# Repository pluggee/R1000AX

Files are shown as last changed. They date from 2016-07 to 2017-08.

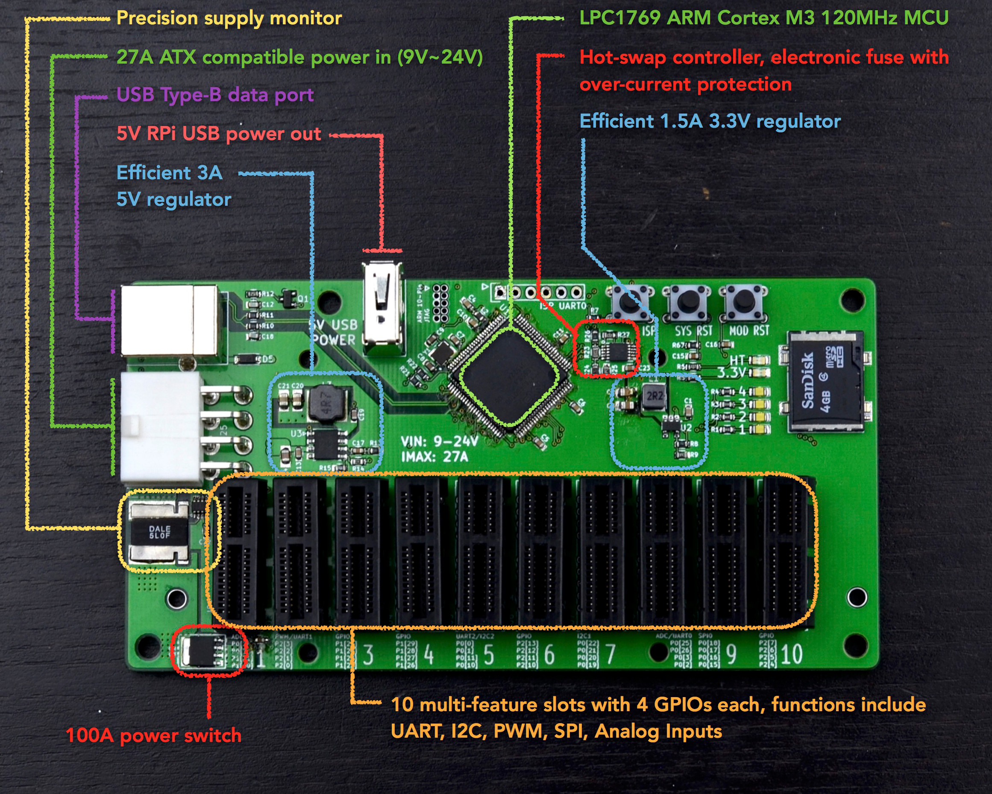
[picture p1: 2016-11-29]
doc/R1000A-10 Illustration.jpg

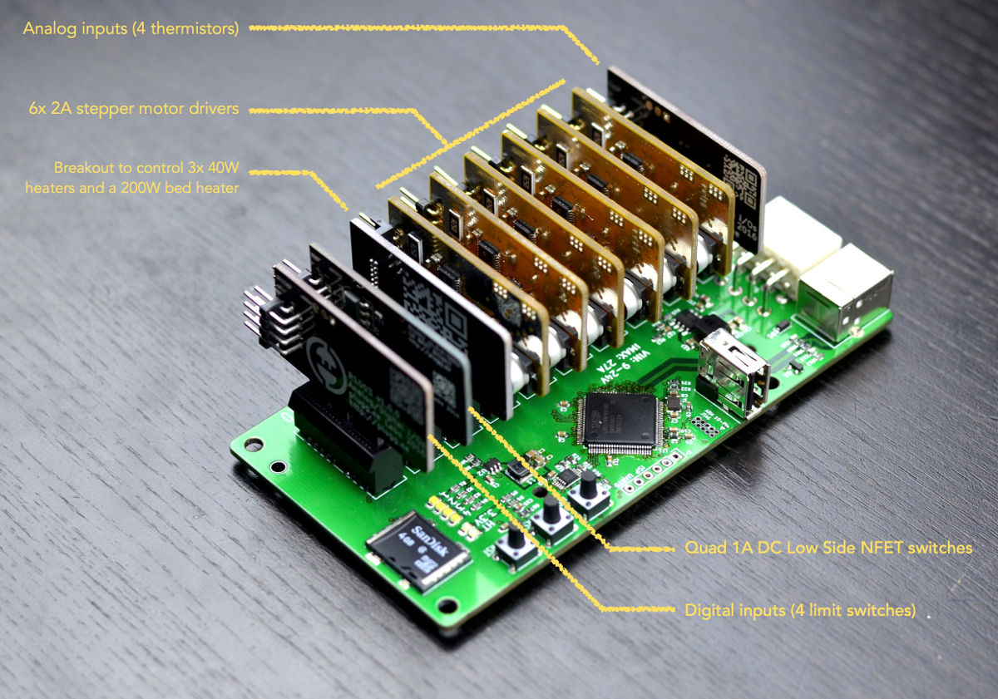
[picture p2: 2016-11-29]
doc/R1000A-10-populated.jpg

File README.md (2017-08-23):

JuicyBoard Robotics Platform
=======================
Overview
--------

This repository contains all PCB and firmware design resources for the R1000 robotics platform base boards and modules

File Structure
--------------
<pre>
(d) pcb	        : KiCAD PCB files
(d) firmware    : firmare for all modules
(d) doc         : documentation
(f) README.md   : Markdown README file
</pre>

Boards
------
Feature Boards
<pre>
R1000A 	        : Base Platform Board (2 variants, R1000AX and R1000A)
R1001		: Cascadable Stepper Motor Driver
R1002		: Quad 1A DC Low Side NFET Control Switches
R1003		: Analog/Digital I/O (Analog/Digital)
R1004		: Inertial Measurement Unit (IMU) Breakout
R1005		: General Purpose Breakout/Extension
R1006 		: SD Card
R1007		: Quad 20A DC Low Side NFET Control Switches
R1008		: Dual/Quad PT100 Platinum RTD temperature sensing module
</pre>
Adapters
<pre>
R1200		: Stepper Motor Master/Slave Bond
</pre>
Interposers
<pre>
R1100           : C.H.I.P. Pro Interposer with Host USB 2.0 and MicroSD
R1101           : particle.io photon Interposer
R1102           : particle.io electron Interposer
R1103           : Raspberry Pi data/power Interposer
</pre>
Special Boards
<pre>
R1000DBG	: Busy Bee Debug/Programming Board
</pre>
Setup Steps
-----------
Make sure to do the following before starting a project

1. Clone (or update) [KiCADLibs](https://github.com/pluggee/KiCADLibs) locally IN THE SAME DIRECTORY AS THIS REPO, this will include the required schematic symbols
2. Clone (or update) [pack3d](https://github.com/pluggee/pack3d) repo, this will include 3D models for PCB 3D view
3. Set KISYS3DMOD variable to point to your local **pack3d** repo, you can do this in the main KiCAD window by

**Preferences** -> **Configure Paths**

License
-------
R1000A board design files are released under the GNU GPL v3, which you can find at <http://www.gnu.org/licenses/gpl-3.0.en.html>,
Check License.md for more details.

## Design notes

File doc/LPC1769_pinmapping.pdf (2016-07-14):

Pin Name

LQFP100 Pin

Smoothie Board Reserved

Reconfgurable?

ADC Input

I2C

SPI

TDO/SWO

1

1
TDI

2

1
TMS/SWDIO

3

1
TRST

4

1
TCK/SWDCLK

5

1
P0[26]/AD0[3]/AOUT/RXD3

6

1

1
P0[25]/AD0[2]/I2SRX_SDA/TXD3

7

1

1
P0[24]/AD0[1]/I2SRX_WS/CAP3[1]

8

1

1
P0[23]/AD0[0]/I2SRX_CLK/CAP3[0]

9

1

1
10

1
11

1
VREFP | 12

1
n.c. | 13

1
RSTOUT | 14

1
VREFN | 15

1
RTCX1 | 16

1
RESET | 17

1
RTCX2 | 18

1
VBAT | 19

1
P1[31]/SCK1/AD0[5] | 20

1

1
| 21

1

1
XTAL1 | 22

1
XTAL2 | 23

1
P0[28]/SCL0/USB_SCL | 24

1
P0[27]/SDA0/USB_SDA | 25

1
P3[26]/STCLK/MAT0[1]/PWM1[3] | 26

1
P3[25]/MAT0[0]/PWM1[2] | 27

1
| 28

1
P0[29]/USB_D+ | 29

1
P0[30]/USB_D | 30

1
| 31

1
P1[18]/USB_UP_LED/PWM1[1]/CAP1[0] | 32

1

VDDA VSSA

P1[30]/VBUS/AD0[4] VDD(3V3) VSS

33

1
P1[20]/MCI0/PWM1[2]/SCK0 | 34

1
P1[21]/MCABORT/PWM1[3]/SSEL0 | 35

1
P1[22]/MCOB0/USB_PWRD/MAT1[0] | 36

1
P1[23]/MCI1/PWM1[4]/MISO0 | 37

1

1
P1[24]/MCI2/PWM1[5]/MOSI0 | 38

1

1
P1[25]/MCOA1/MAT1[1] | 39

1
P1[26]/MCOB1/PWM1[6]/CAP0[0] | 40

1
| 41

1
| 42

1
| 43

1
P1[28]/MCOA2/PCAP1[0]/MAT0[0] | 44

1
P1[29]/MCOB2/PCAP1[1]/MAT0[1] | 45

1
P0[0]/RD1/TXD3/SDA1 | 46

1

1
P0[1]/TD1/RXD3/SCL1 | 47

1

1
P0[10]/TXD2/SDA2/MAT3[0] | 48

1

1
P0[11]/RXD2/SCL2/MAT3[1] | 49

1

1
P2[13]/EINT3/I2STX_SDA | 50

1
P2[12]/EINT2/I2STX_WS | 51

1
P2[11]/EINT1/I2STX_CLK | 52

1
P2[10]/EINT0/NMI | 53

1
| 54

1
| 55

1
P0[22]/RTS1/TD1 | 56

1
P0[21]/RI1/RD1 | 57

1
P0[20]/DTR1/SCL1 | 58

1

1
P0[19]/DSR1/SDA1 | 59

1

1
P0[18]/DCD1/MOSI0/MOSI | 60

1

1
P0[17]/CTS1/MISO0/MISO | 61

1

1
P0[15]/TXD1/SCK0/SCK | 62

1

1
P0[16]/RXD1/SSEL0/SSEL | 63

1

1
P2[9]/USB_CONNECT/RXD2 | 64

1
P2[8]/TD2/TXD2 | 65

1
P2[7]/RD2/RTS1 | 66

1
P2[6]/PCAP1[0]/RI1/TRACECLK | 67

1
P2[5]/PWM1[6]/DTR1/TRACEDATA[0] | 68

1
P2[4]/PWM1[5]/DSR1/TRACEDATA[1] | 69

1
P2[3]/PWM1[4]/DCD1/TRACEDATA[2] | 70

1
| 71

1
| 72

1
P2[2]/PWM1[3]/CTS1/TRACEDATA[3] | 73

1
P2[1]/PWM1[2]/RXD1 | 74

1
P2[0]/PWM1[1]/TXD1 | 75

1

P1[19]/MCOA0/USB_PPWR/CAP1[1] VSS VDD(REG)(3V3)***

# P1[27]/CLKOUT/USB_OVRCR/CAP0[1] VDD(3V3) VSS VDD(3V3) VSS

P0[9]/I2STX_SDA/MOSI1/MAT2[3] | 76

1
P0[8]/I2STX_WS/MISO1/MAT2[2] | 77

1
P0[7]/I2STX_CLK/SCK1/MAT2[1] | 78

1
P0[6]/I2SRX_SDA/SSEL1/MAT2[0] | 79

1
P0[5]/I2SRX_WS/TD2/CAP2[1] | 80

1
P0[4]/I2SRX_CLK/RD2/CAP2[0] | 81

1
P4[28]/RX_MCLK/MAT2[0]/TXD3 | 82

1
| 83

1
| 84

1
P4[29]/TX_MCLK/MAT2[1]/RXD3 | 85

1
P1[17]/ENET_MDIO | 86

1
P1[16]/ENET_MDC | 87

1
P1[15]/ENET_REF_CLK | 88

1
P1[14]/ENET_RX_ER | 89

1
P1[10]/ENET_RXD1 | 90

1
P1[9]/ENET_RXD0 | 91

1
P1[8]/ENET_CRS | 92

1
P1[4]/ENET_TX_EN | 93

1
P1[1]/ENET_TXD1 | 94

1
P1[0]/ENET_TXD0 | 95

1
| 96

1
| 97

1
P0[2]/TXD0/AD0[7] | 98

1

1
P0[3]/RXD0/AD0[6] | 99

1

1
RTCK | 100

1

# VSS VDD(REG)(3V3) VDD(3V3) VSS

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
NC-JTAG
NC-JTAG
NC-JTAG
NC-JTAG
NC-JTAG
TH4
TH3
TH2
TH1
3.3V
GND
3.3V
NC
doesn’t exist in symbol
GND
NC
Reset button
NC
3.3V
P1_31
P1_30
Crystal
Crystal
I2C | Verify firmware
I2C | Verify firmware
P3_26
P3_25
3.3V
USB
USB
GND
LED1

LED2
LED3
LED4
P1_22
P1_23
X_MIN
X_MAX
Y_MIN
GND
3.3V
Y_MAX
Z_MIN
Z_MAX
POT_SDA | should be, check firmware option ability
POT_SCL | should be, check firmware option ability
EN2
DIR2
DIR5
PLAY/P2_12
P2_11
ISP_BOOT/P2_10
3.3V
GND
DIR4
EN4
DIR3
EN3
Panel SPI
Panel SPI
Panel SPI
Panel SPI
P2_9
STP5
P2_7
P2_6
P2_5
P2_4
ST4
3.3V
GND
ST3
ST2
ST1

SPI_SD
SPI_SD
SPI_SD
SPI_SD
DIR1
EN1
PLAY_LED
GND
3.3V
EN5
Ethernet
Ethernet
Ethernet
Ethernet
Ethernet
Ethernet
Ethernet
Ethernet
Ethernet
Ethernet
3.3V
GND
TX_0 | not sure
RX_0 | not sure
NC

Pin Name | LQFP¹⁰⁰ Pin | | | | | | | | | | | | Func | Net Name
P0[9]/I2STX_SDA/MOSI1/MAT2[3] | 76 | 1 | | | | | SPI_SD | P0[9] | I2STX_SDA | MOSI1 | MAT2[3] | 0.11 SPI1 | | J01.PX1.A12
P0[8]/I2STX_WS/MISO1/MAT2[2] | 77 | 1 | | | | | SPI_SD | P0[8] | I2STX_WS | MISO1 | MAT2[2] | 0.12 SPI1 | | J01.PX2.A13
P0[7]/I2STX_CLK/SCK1/MAT2[1] | 78 | 1 | | | | | SPI_SD | P0[7] | I2STX_CLK | SCK1 | MAT2[1] | 0.13 SPI1 | | J01.PX4.A15
P0[6]/I2SRX_SDA/SSEL1/MAT2[0] | 79 | 1 | | | | | SPI_SD | P0[6] | I2SRX_SDA | SSEL1 | MAT2[0] | 0.14 SPI1 | | J01.PX3.A14
P0[23]/AD0[0]/I2SRX_CLK/CAP3[0] | 9 | | 1 | 1 | | | TH1 | P0[23] | AD0[0] | | | 1.11ADC/UART | | J02.PX1.A12
P0[24]/AD0[1]/I2SRX_WS/CAP3[1] | 8 | | 1 | 1 | | | TH2 | P0[24] | AD0[1] | | | 1.12ADC/UART | | J02.PX2.A13
P0[26]/AD0[3]/AOUT/RXD3 | 6 | | 1 | 1 | | | TH4 | P0[26] | AD0[3] | AOUT | RXD3 | 1.13ADC/UART | | J02.PX3.A14
P0[25]/AD0[2]/I2SRX_SDA/TXD3 | 7 | | 1 | 1 | | | TH3 | P0[25] | AD0[2] | | TXD3 | 1.14ADC/UART | | J02.PX4.A15
P1[31]/SCK1/AD0[5] | 20 | | 1 | 1 | | | P1_31 | P1[31] | SCK1 | AD0[5] | | 1.21ADC/UART | | J03.PX1.A12
P1[30]/VBUS/AD0[4] | 21 | | 1 | 1 | | | P1_30 | P1[30] | VBUS | AD0[4] | | 1.22ADC/UART | | J03.PX2.A13
P0[3]/RXD0/AD0[6] | 99 | | 1 | 1 | | | RX_0 | P0[3] | RXD0 | AD0[6] | | 1.23ADC/UART | | J03.PX3.A14
P0[2]/TXD0/AD0[7] | 98 | | 1 | 1 | | | TX_0 | P0[2] | TXD0 | AD0[7] | | 1.24ADC/UART | | J03.PX4.A15
P2[7]/RD2/RTS1 | 66 | | 1 | | | | P2_7 | P2[7] | | | | 1.31 UART | | J04.PX1.A12
P2[6]/PCAP1[0]/RI1/TRACECLK | 67 | | 1 | | | | P2_6 | P2[6] | | | | 1.32 UART | | J04.PX2.A13
P2[9]/USB_CONNECT/RXD2 | 64 | | 1 | | | | P2_9 | P2[9] | | RXD2 | | 1.33 UART | | J04.PX3.A14
P2[8]/TD2/TXD2 | 65 | | 1 | | | | STP5 | P2[8] | | TXD2 | | 1.34 UART | | J04.PX4.A15
P2[3]/PWM1[4]/DCD1/TRACEDATA[2] | 70 | | 1 | | | | ST4 | P2[3] | PWM1[4] | | | 1.41 UART/PWM | | J05.PX1.A12
P2[2]/PWM1[3]/CTS1/TRACEDATA[3] | 73 | | 1 | | | | ST3 | P2[2] | PWM1[3] | | | 1.42 UART/PWM | | J05.PX2.A13
P2[1]/PWM1[2]/RXD1 | 74 | | 1 | | | | ST2 | P2[1] | PWM1[2] | RXD1 | | 1.43 UART/PWM | | J05.PX3.A14
P2[0]/PWM1[1]/TXD1 | 75 | | 1 | | | | ST1 | P2[0] | PWM1[1] | TXD1 | | 1.44 UART/PWM | | J05.PX4.A15
P0[4]/I2SRX_CLK/RD2/CAP2[0] | 81 | | 1 | | | | EN1 | P0[4] | | | | 1.51 UART/CAN | | J06.PX1.A12
P0[5]/I2SRX_WS/TD2/CAP2[1] | 80 | | 1 | | | | DIR1 | P0[5] | | | | 1.52 UART/CAN | | J06.PX2.A13
P4[29]/TX_MCLK/MAT2[1]/RXD3 | 85 | | 1 | | | | EN5 | P4[29] | | | RXD3 | 1.53 UART/CAN | | J06.PX3.A14
P4[28]/RX_MCLK/MAT2[0]/TXD3 | 82 | | 1 | | | | PLAY_LED | P4[28] | | | TXD3 | 1.54 UART/CAN | | J06.PX4.A15
P0[18]/DCD1/MOSI0/MOSI | 60 | | 1 | | | 1 | Panel SPI | P0[18] | | MOSI0 | | 2.11 SPI0 | | J07.PX1.A12
P0[17]/CTS1/MISO0/MISO | 61 | | 1 | | | 1 | Panel SPI | P0[17] | | MISO0 | | 2.12 SPI0 | | J07.PX2.A13
P0[15]/TXD1/SCK0/SCK | 62 | | 1 | | | 1 | Panel SPI | P0[15] | | SCK0 | | 2.13 SPI0 | | J07.PX4.A15
P0[16]/RXD1/SSEL0/SSEL | 63 | | 1 | | | 1 | Panel SPI | P0[16] | | SSEL0 | SSEL | 2.14 SPI0 | | J07.PX3.A14
P1[18]/USB_UP_LED/PWM1[1]/CAP1[0] | 32 | | 1 | | | | LED1 | P1[18] | | PWM1[1] | | 3.11 PWM | | J08.PX1.A12
P1[20]/MCI0/PWM1[2]/SCK0 | 34 | | 1 | | | | LED3 | P1[20] | | PWM1[2] | | 3.12 PWM | | J08.PX2.A13
P2[5]/PWM1[6]/DTR1/TRACEDATA[0] | 68 | | 1 | | | | P2_5 | P2[5] | PWM1[6] | | | 3.13 PWM | | J08.PX3.A14
P2[4]/PWM1[5]/DSR1/TRACEDATA[1] | 69 | | 1 | | | | P2_4 | P2[4] | PWM1[5] | | | 3.14 PWM | | J08.PX4.A15
P0[22]/RTS1/TD1 | 56 | | 1 | | | | DIR4 | P0[22] | | | | 4.11 I2C/CAN | | J09.PX1.A12
P0[21]/RI1/RD1 | 57 | | 1 | | | | EN4 | P0[21] | | | | 4.12 I2C/CAN | | J09.PX2.A13
P0[20]/DTR1/SCL1 | 58 | | 1 | | 1 | | DIR3 | P0[20] | | SCL1 | | 4.13 I2C/CAN | | J09.PX3.A14
P0[19]/DSR1/SDA1 | 59 | | 1 | | 1 | | EN3 | P0[19] | | SDA1 | | 4.14 I2C/CAN | | J09.PX4.A15
P0[0]/RD1/TXD3/SDA1 | 46 | | 1 | | 1 | | POT_SDA | P0[0] | | | | 4.21 I2C | | J10.PX1.A12
P0[1]/TD1/RXD3/SCL1 | 47 | | 1 | | 1 | | POT_SCL | P0[1] | | | | 4.22 I2C | | J10.PX2.A13
P0[11]/RXD2/SCL2/MAT3[1] | 49 | | 1 | | 1 | | DIR2 | P0[11] | RXD2 | SCL2 | | 4.23 I2C | | J10.PX3.A14
P0[10]/TXD2/SDA2/MAT3[0] | 48 | | 1 | | 1 | | EN2 | P0[10] | TXD2 | SDA2 | | 4.24 I2C | | J10.PX4.A15
P2[13]/EINT3/I2STX_SDA | 50 | | 1 | | | | DIR5 | P2[13] | | | | 5.11 GPIO | | J11.PX1.A12
P2[12]/EINT2/I2STX_WS | 51 | | 1 | | | | PLAY/P2_12 | P2[12] | | | | 5.12 GPIO | | J11.PX2.A13
P2[11]/EINT1/I2STX_CLK | 52 | | 1 | | | | P2_11 | P2[11] | | | | 5.13 GPIO | | J11.PX3.A14
P2[10]/EINT0/NMI | 53 | | 1 | | | | ISP_BOOT/P2_10 | P2[10] | | | | 5.14 GPIO | | J11.PX4.A15
P3[26]/STCLK/MAT0[1]/PWM1[3] | 26 | | 1 | | | | P3_26 | P3[26] | | | | 5.21 GPIO | | J12.PX1.A12
P3[25]/MAT0[0]/PWM1[2] | 27 | | 1 | | | | P3_25 | P3[25] | | | | 5.22 GPIO | | J12.PX2.A13
P1[19]/MCOA0/USB_PPWR/CAP1[1] | 33 | | 1 | | | | LED2 | P1[19] | | | | 5.23 GPIO | | J12.PX3.A14
P1[21]/MCABORT/PWM1[3]/SSEL0 | 35 | | 1 | | | | LED4 | P1[21] | | | | 5.24 GPIO | | J12.PX4.A15
P1[22]/MCOB0/USB_PWRD/MAT1[0] | 36 | | 1 | | | | P1_22 | P1[22] | | | | 5.31 GPIO | | J13.PX1.A12
P1[23]/MCI1/PWM1[4]/MISO0 | 37 | | 1 | | | 1 | P1_23 | P1[23] | | | | 5.32 GPIO | | J13.PX2.A13
P1[24]/MCI2/PWM1[5]/MOSI0 | 38 | | 1 | | | 1 | X_MIN | P1[24] | | | | 5.33 GPIO | | J13.PX3.A14
P1[25]/MCOA1/MAT1[1] | 39 | | 1 | | | | X_MAX | P1[25] | | | | 5.34 GPIO | | J13.PX4.A15
P1[26]/MCOB1/PWM1[6]/CAP0[0] | 40 | | 1 | | | | Y_MIN | P1[26] | | | | 5.41 GPIO | | J14.PX1.A12
P1[27]/CLKOUT/USB_OVRCR/CAP0[1] | 43 | | 1 | | | | Y_MAX | P1[27] | | | | 5.42 GPIO | | J14.PX2.A13
P1[28]/MCOA2/PCAP1[0]/MAT0[0] | 44 | | 1 | | | | Z_MIN | P1[28] | | | | 5.43 GPIO | | J14.PX3.A14
P1[29]/MCOB2/PCAP1[1]/MAT0[1] | 45 | | 1 | | | | Z_MAX | P1[29] | | | | 5.44 GPIO | | J14.PX4.A15
P1[17]/ENET_MDIO | 86 | 1 | | | | | Ethernet | P1[17] | ENET_MDIO | | | 6.11 GPIO | | J15.PX1.A12
P1[16]/ENET_MDC | 87 | 1 | | | | | Ethernet | P1[16] | ENET_MDC | | | 6.12 GPIO | | J15.PX2.A13
P1[15]/ENET_REF_CLK | 88 | 1 | | | | | Ethernet | P1[15] | ENET_REF_CLK | | | 6.13 GPIO | | J15.PX3.A14
P1[14]/ENET_RX_ER | 89 | 1 | | | | | Ethernet | P1[14] | ENET_RX_ER | | | 6.14 GPIO | | J15.PX4.A15
P1[10]/ENET_RXD1 | 90 | 1 | | | | | Ethernet | P1[10] | ENET_RXD1 | | | 6.21 GPIO | | J16.PX1.A12
P1[9]/ENET_RXD0 | 91 | 1 | | | | | Ethernet | P1[9] | ENET_RXD0 | | | 6.22 GPIO | | J16.PX2.A13
P1[8]/ENET_CRS | 92 | 1 | | | | | Ethernet | P1[8] | ENET_CRS | | | 6.23 GPIO | | J16.PX3.A14
P1[4]/ENET_TX_EN | 93 | 1 | | | | | Ethernet | P1[4] | ENET_TX_EN | | | 6.24 GPIO | | J16.PX4.A15
TDO/SWO | 1 | 1 | | | | | NC-JTAG | TDO | SWO
TDI | 2 | 1 | | | | | NC-JTAG | TDI
TMS/SWDIO | 3 | 1 | | | | | NC-JTAG | TMS | SWDIO
TRST | 4 | 1 | | | | | NC-JTAG | TRST
TCK/SWDCLK | 5 | 1 | | | | | NC-JTAG | TCK | SWDCLK
VDDA | 10 | 1 | | | | | 3.3V | VDDA
VSSA | 11 | 1 | | | | | GND | VSSA
VREFP | 12 | 1 | | | | | 3.3V | VREFP
n.c. | 13 | 1 | | | | | NC | n.c.
RSTOUT | 14 | 1 | | | | | NC | RSTOUT
VREFN | 15 | 1 | | | | | GND | VREFN
RTCX1 | 16 | 1 | | | | | NC | RTCX1
RESET | 17 | 1 | | | | | Reset button | RESET
RTCX2 | 18 | 1 | | | | | NC | RTCX2
VBAT | 19 | 1 | | | | | 3.3V | VBAT
XTAL1 | 22 | 1 | | | | | Crystal | XTAL1
XTAL2 | 23 | 1 | | | | | Crystal | XTAL2
P0[28]/SCL0/USB_SCL | 24 | 1 | | | | | I2C | P0[28] | SCL0 | USB_SCL
P0[27]/SDA0/USB_SDA | 25 | 1 | | | | | I2C | P0[27] | SDA0 | USB_SDA
VDD(3V3) | 28 | 1 | | | | | 3.3V | VDD(3V3)
P0[29]/USB_D+ | 29 | 1 | | | | | USB | P0[29] | USB_D+
P0[30]/USB_D | 30 | 1 | | | | | USB | P0[30] | USB_D
VSS | 31 | 1 | | | | | GND | VSS
VSS | 41 | 1 | | | | | GND | VSS
VDD(REG)(3V3)*** | 42 | 1 | | | | | 3.3V | VDD(REG)(3V3)***
VDD(3V3) | 54 | 1 | | | | | 3.3V | VDD(3V3)
VSS | 55 | 1 | | | | | GND | VSS
VDD(3V3) | 71 | 1 | | | | | 3.3V | VDD(3V3)
VSS | 72 | 1 | | | | | GND | VSS
VSS | 83 | 1 | | | | | GND | VSS
VDD(REG)(3V3) | 84 | 1 | | | | | 3.3V | VDD(REG)(3V3)
P1[1]/ENET_TXD1 | 94 | 1 | | | | | Ethernet | P1[1] | ENET_TXD1
P1[0]/ENET_TXD0 | 95 | 1 | | | | | Ethernet | P1[0] | ENET_TXD0
VDD(3V3) | 96 | 1 | | | | | 3.3V | VDD(3V3)
VSS | 97 | 1 | | | | | GND | VSS
RTCK | 100 | 1 | | | | | NC | RTCK

Smoothie Board Reserved?

Reconfgurable?

A

D

C Input

I2C

SPI

Smoothie Function

F1

F2

F3

F4

PEX

Group

Pin Name | L Q

F

P10

0

Pin

Y | R/L
NC | 13 | -50 L
P0[0]/RD1/TXD3/SDA1 | 46 | 50 L
P0[1]/TD1/RXD3/SCL1 | 47 | 150 L
P0[10]/TXD2/SDA2/MAT3[0] | 48 | 250 L
P0[11]/RXD2/SCL2/MAT3[1] | 49 | 350 L
P0[15]/TXD1/SCK0/SCK | 62 | 450 L
P0[16]/RXD1/SSEL0/SSEL | 63 | 550 L
P0[17]/CTS1/MISO0/MISO | 61 | 650 L
P0[18]/DCD1/MOSI0/MOSI | 60 | 750 L
P0[19]/DSR1/SDA1 | 59 | 850 L
P0[2]/TXD0/AD0[7] | 98 | 950 L
P0[20]/DTR1/SCL1 | 58 | 1050 L
P0[21]/RI1/RD1 | 57 | 1150 L
P0[22]/RTS1/TD1 | 56 | 1250 L
P0[23]/AD0[0]/I2SRX_CLK/CAP3[0] | 9 | 1350 L
P0[24]/AD0[1]/I2SRX_WS/CAP3[1] | 8 | 1450 L
P0[25]/AD0[2]/I2SRX_SDA/TXD3 | 7 | 1550 L
P0[26]/AD0[3]/AOUT/RXD3 | 6 | 1650 L
P0[27]/SDA0/USB_SDA | 25 | 1750 L
P0[28]/SCL0/USB_SCL | 24 | 1850 L
P0[29]/USB_D+ | 29 | 1950 L
P0[3]/RXD0/AD0[6] | 99 | 2050 L
P0[30]/USB_D | 30 | 2150 L
P0[4]/I2SRX_CLK/RD2/CAP2[0] | 81 | 2250 L
P0[5]/I2SRX_WS/TD2/CAP2[1] | 80 | 2350 L
P0[6]/I2SRX_SDA/SSEL1/MAT2[0] | 79 | 2450 L
P0[7]/I2STX_CLK/SCK1/MAT2[1] | 78 | 2550 L
P0[8]/I2STX_WS/MISO1/MAT2[2] | 77 | 2650 L
P0[9]/I2STX_SDA/MOSI1/MAT2[3] | 76 | 2750 L
P1[0]/ENET_TXD0 | 95 | 2850 L
P1[1]/ENET_TXD1 | 94 | 2950 L
P1[10]/ENET_RXD1 | 90 | 3050 L
P1[14]/ENET_RX_ER | 89 | 3150 L
P1[15]/ENET_REF_CLK | 88 | 3250 L
P1[16]/ENET_MDC | 87 | 3350 L
P1[17]/ENET_MDIO | 86 | 3450 L
P1[18]/USB_UP_LED/PWM1[1]/CAP1[0] | 32 | 3550 L
| 33 | 3650 L
P1[20]/MCI0/PWM1[2]/SCK0 | 34 | 3750 L

P1[19]/MCOA0/USB_PPWR/CAP1[1]

P1[21]/MCABORT/PWM1[3]/SSEL0 | 35 | 3850 L
P1[22]/MCOB0/USB_PWRD/MAT1[0] | 36 | 3950 L
P1[23]/MCI1/PWM1[4]/MISO0 | 37 | 4050 L
P1[24]/MCI2/PWM1[5]/MOSI0 | 38 | 4150 L
P1[25]/MCOA1/MAT1[1] | 39 | 4250 L
P1[26]/MCOB1/PWM1[6]/CAP0[0] | 40 | 4350 L
| 43 | 4450 L
P1[28]/MCOA2/PCAP1[0]/MAT0[0] | 44 | 4550 L
P1[29]/MCOB2/PCAP1[1]/MAT0[1] | 45 | 4650 L
| 21 | 4750 L
P1[31]/SCK1/AD0[5] | 20 | 4850 L
P1[4]/ENET_TX_EN | 93 | 4950 L
P1[8]/ENET_CRS | 92 | 5050 L
P1[9]/ENET_RXD0 | 91 | 5150 L
P2[0]/PWM1[1]/TXD1 | 75 | 5250 L
P2[1]/PWM1[2]/RXD1 | 74 | 5350 L
P2[10]/EINT0/NMI | 53 | 5450 L
P2[11]/EINT1/I2STX_CLK | 52 | 5550 L
P2[12]/EINT2/I2STX_WS | 51 | 5650 L
P2[13]/EINT3/I2STX_SDA | 50 | 5750 L
P2[2]/PWM1[3]/CTS1/TRACEDATA[3] | 73 | 5850 L
P2[3]/PWM1[4]/DCD1/TRACEDATA[2] | 70 | 5950 L
P2[4]/PWM1[5]/DSR1/TRACEDATA[1] | 69 | 6050 L
P2[5]/PWM1[6]/DTR1/TRACEDATA[0] | 68 | 6150 L
P2[6]/PCAP1[0]/RI1/TRACECLK | 67 | 6250 L
P2[7]/RD2/RTS1 | 66 | 6350 L
P2[8]/TD2/TXD2 | 65 | 6450 L
P2[9]/USB_CONNECT/RXD2 | 64 | 6550 L
P3[25]/MAT0[0]/PWM1[2] | 27 | 6650 L
P3[26]/STCLK/MAT0[1]/PWM1[3] | 26 | 6750 L
P4[28]/RX_MCLK/MAT2[0]/TXD3 | 82 | 6850 L
P4[29]/TX_MCLK/MAT2[1]/RXD3 | 85 | 6950 L
RESET | 17 | 7050 L
RSTOUT | 14 | 7150 L
RTCK | 100 | 7250 L
RTCX1 | 16 | 7350 L
RTCX2 | 18 | 7450 L
TCK/SWDCLK | 5 | 7550 L
TDI | 2 | 7650 L
TDO/SWO | 1 | 7750 L
TMS/SWDIO | 3 | 7850 L
TRST | 4 | 7950 L
VBAT | 19 | 8050 L

P1[27]/CLKOUT/USB_OVRCR/CAP0[1]

P1[30]/VBUS/AD0[4]

| 28 | 8150

L
| 54 | 8250

L
| 71 | 8350

L
| 96 | 8450

L
| 84 | 8550

L
| 42 | 8650

L
| 10 | 8750

L
VREFN | 15 | 8850

L
VREFP | 12 | 8950

L
| 31 | 9050

L
| 41 | 9150

L
| 55 | 9250

L
| 72 | 9350

L
| 83 | 9450

L
| 97 | 9550

L
| 11 | 9650

L
XTAL1 | 22 | 9750

L
XTAL2 | 23 | 9850

L

VDD(3V3) VDD(3V3) VDD(3V3) VDD(3V3) VDD(REG)(3V3) VDD(REG)(3V3)*** VDDA VSS VSS VSS VSS VSS VSS VSSA

X NC 13 1000 -50 L 50 50 1 1 B
X P0[0]/RD1/TXD3/SDA1 46 1000 50 L 50 50 1 1 B
X P0[1]/TD1/RXD3/SCL1 47 1000 150 L 50 50 1 1 B
X P0[10]/TXD2/SDA2/MAT3[0] 48 1000 250 L 50 50 1 1 B X P0[11]/RXD2/SCL2/MAT3[1] 49 1000 350 L 50 50 1 1 B X P0[15]/TXD1/SCK0/SCK 62 1000 450 L 50 50 1 1 B
X P0[16]/RXD1/SSEL0/SSEL 63 1000 550 L 50 50 1 1 B X P0[17]/CTS1/MISO0/MISO 61 1000 650 L 50 50 1 1 B X P0[18]/DCD1/MOSI0/MOSI 60 1000 750 L 50 50 1 1 B X P0[19]/DSR1/SDA1 59 1000 850 L 50 50 1 1 B
X P0[2]/TXD0/AD0[7] 98 1000 950 L 50 50 1 1 B
X P0[20]/DTR1/SCL1 58 1000 1050 L 50 50 1 1 B
X P0[21]/RI1/RD1 57 1000 1150 L 50 50 1 1 B
X P0[22]/RTS1/TD1 56 1000 1250 L 50 50 1 1 B
X P0[23]/AD0[0]/I2SRX_CLK/CAP3[0] 9 1000 1350 L 50 50 1 1 B X P0[24]/AD0[1]/I2SRX_WS/CAP3[1] 8 1000 1450 L 50 50 1 1 B X P0[25]/AD0[2]/I2SRX_SDA/TXD3 7 1000 1550 L 50 50 1 1 B X P0[26]/AD0[3]/AOUT/RXD3 6 1000 1650 L 50 50 1 1 B
X P0[27]/SDA0/USB_SDA 25 1000 1750 L 50 50 1 1 B
X P0[28]/SCL0/USB_SCL 24 1000 1850 L 50 50 1 1 B
X P0[29]/USB_D+ 29 1000 1950 L 50 50 1 1 B
X P0[3]/RXD0/AD0[6] 99 1000 2050 L 50 50 1 1 B
X P0[30]/USB_D 30 1000 2150 L 50 50 1 1 B
X P0[4]/I2SRX_CLK/RD2/CAP2[0] 81 1000 2250 L 50 50 1 1 B X P0[5]/I2SRX_WS/TD2/CAP2[1] 80 1000 2350 L 50 50 1 1 B X P0[6]/I2SRX_SDA/SSEL1/MAT2[0] 79 1000 2450 L 50 50 1 1 B X P0[7]/I2STX_CLK/SCK1/MAT2[1] 78 1000 2550 L 50 50 1 1 B X P0[8]/I2STX_WS/MISO1/MAT2[2] 77 1000 2650 L 50 50 1 1 B X P0[9]/I2STX_SDA/MOSI1/MAT2[3] 76 1000 2750 L 50 50 1 1 B X P1[0]/ENET_TXD0 95 1000 2850 L 50 50 1 1 B
X P1[1]/ENET_TXD1 94 1000 2950 L 50 50 1 1 B
X P1[10]/ENET_RXD1 90 1000 3050 L 50 50 1 1 B
X P1[14]/ENET_RX_ER 89 1000 3150 L 50 50 1 1 B X P1[15]/ENET_REF_CLK 88 1000 3250 L 50 50 1 1 B
X P1[16]/ENET_MDC 87 1000 3350 L 50 50 1 1 B
X P1[17]/ENET_MDIO 86 1000 3450 L 50 50 1 1 B
X P1[18]/USB_UP_LED/PWM1[1]/CAP1[0] 32 1000 3550 L 50 50 1 1 B X P1[19]/MCOA0/USB_PPWR/CAP1[1] 33 1000 3650 L 50 50 1 1 B
X P1[20]/MCI0/PWM1[2]/SCK0 34 1000 3750 L 50 50 1 1 B

X P1[21]/MCABORT/PWM1[3]/SSEL0 35 1000 3850 L 50 50 1 1 B X P1[22]/MCOB0/USB_PWRD/MAT1[0] 36 1000 3950 L 50 50 1 1 B X P1[23]/MCI1/PWM1[4]/MISO0 37 1000 4050 L 50 50 1 1 B
X P1[24]/MCI2/PWM1[5]/MOSI0 38 1000 4150 L 50 50 1 1 B
X P1[25]/MCOA1/MAT1[1] 39 1000 4250 L 50 50 1 1 B
X P1[26]/MCOB1/PWM1[6]/CAP0[0] 40 1000 4350 L 50 50 1 1 B
X P1[27]/CLKOUT/USB_OVRCR/CAP0[1] 43 1000 4450 L 50 50 1 1 B X P1[28]/MCOA2/PCAP1[0]/MAT0[0] 44 1000 4550 L 50 50 1 1 B X P1[29]/MCOB2/PCAP1[1]/MAT0[1] 45 1000 4650 L 50 50 1 1 B X P1[30]/VBUS/AD0[4] 21 1000 4750 L 50 50 1 1 B
X P1[31]/SCK1/AD0[5] 20 1000 4850 L 50 50 1 1 B
X P1[4]/ENET_TX_EN 93 1000 4950 L 50 50 1 1 B
X P1[8]/ENET_CRS 92 1000 5050 L 50 50 1 1 B
X P1[9]/ENET_RXD0 91 1000 5150 L 50 50 1 1 B
X P2[0]/PWM1[1]/TXD1 75 1000 5250 L 50 50 1 1 B X P2[1]/PWM1[2]/RXD1 74 1000 5350 L 50 50 1 1 B X P2[10]/EINT0/NMI 53 1000 5450 L 50 50 1 1 B
X P2[11]/EINT1/I2STX_CLK 52 1000 5550 L 50 50 1 1 B
X P2[12]/EINT2/I2STX_WS 51 1000 5650 L 50 50 1 1 B
X P2[13]/EINT3/I2STX_SDA 50 1000 5750 L 50 50 1 1 B
X P2[2]/PWM1[3]/CTS1/TRACEDATA[3] 73 1000 5850 L 50 50 1 1 B X P2[3]/PWM1[4]/DCD1/TRACEDATA[2] 70 1000 5950 L 50 50 1 1 B X P2[4]/PWM1[5]/DSR1/TRACEDATA[1] 69 1000 6050 L 50 50 1 1 B X P2[5]/PWM1[6]/DTR1/TRACEDATA[0] 68 1000 6150 L 50 50 1 1 B X P2[6]/PCAP1[0]/RI1/TRACECLK 67 1000 6250 L 50 50 1 1 B
X P2[7]/RD2/RTS1 66 1000 6350 L 50 50 1 1 B
X P2[8]/TD2/TXD2 65 1000 6450 L 50 50 1 1 B
X P2[9]/USB_CONNECT/RXD2 64 1000 6550 L 50 50 1 1 B
X P3[25]/MAT0[0]/PWM1[2] 27 1000 6650 L 50 50 1 1 B
X P3[26]/STCLK/MAT0[1]/PWM1[3] 26 1000 6750 L 50 50 1 1 B X P4[28]/RX_MCLK/MAT2[0]/TXD3 82 1000 6850 L 50 50 1 1 B X P4[29]/TX_MCLK/MAT2[1]/RXD3 85 1000 6950 L 50 50 1 1 B X RESET 17 1000 7050 L 50 50 1 1 B
X RSTOUT 14 1000 7150 L 50 50 1 1 B
X RTCK 100 1000 7250 L 50 50 1 1 B
X RTCX1 16 1000 7350 L 50 50 1 1 B
X RTCX2 18 1000 7450 L 50 50 1 1 B
X TCK/SWDCLK 5 1000 7550 L 50 50 1 1 B X TDI 2 1000 7650 L 50 50 1 1 B
X TDO/SWO 1 1000 7750 L 50 50 1 1 B X TMS/SWDIO 3 1000 7850 L 50 50 1 1 B X TRST 4 1000 7950 L 50 50 1 1 B
X VBAT 19 1000 8050 L 50 50 1 1 B

X VDD(3V3) 28 1000 8150 L 50 50 1 1 B X VDD(3V3) 54 1000 8250 L 50 50 1 1 B
X VDD(3V3) 71 1000 8350 L 50 50 1 1 B
X VDD(3V3) 96 1000 8450 L 50 50 1 1 B
X VDD(REG)(3V3) 84 1000 8550 L 50 50 1 1 B X VDD(REG)(3V3)*** 42 1000 8650 L 50 50 1 1 B X VDDA 10 1000 8750 L 50 50 1 1 B
X VREFN 15 1000 8850 L 50 50 1 1 B
X VREFP 12 1000 8950 L 50 50 1 1 B
X VSS 31 1000 9050 L 50 50 1 1 B X VSS 41 1000 9150 L 50 50 1 1 B X VSS 55 1000 9250 L 50 50 1 1 B X VSS 72 1000 9350 L 50 50 1 1 B X VSS 83 1000 9450 L 50 50 1 1 B X VSS 97 1000 9550 L 50 50 1 1 B X VSSA 11 1000 9650 L 50 50 1 1 B X XTAL1 22 1000 9750 L 50 50 1 1 B X XTAL2 23 1000 9850 L 50 50 1 1 B

X PAD2 2 1000 850 200 L 50 50 1 1 B

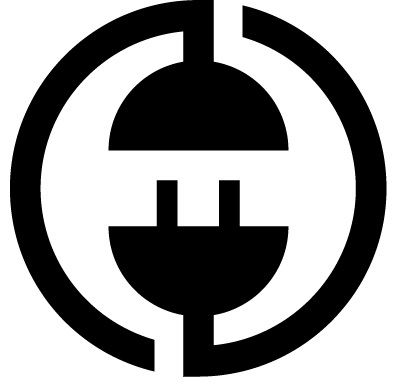
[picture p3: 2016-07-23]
doc/bw_cut.png

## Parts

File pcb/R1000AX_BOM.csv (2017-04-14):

Reference | Quantity | Value | Footprint | Datasheet | Manufacturer | MPN | SKU | Res | Tol | Pwr | C | Vmax | Type | Color
A1 | 1 | ART | Symbols:KiCad-Logo2_12mm_SilkScreen
A2 | 1 | ART | pluggee:pluggeeLabsLogo
A3 | 1 | ART | Symbols:OSHW-Logo_11.4x12mm_SilkScreen
A4 | 1 | ART | Symbols:Symbol_GNU-Logo_SilkscreenTop
A5 | 1 | ART | Symbols:RoHS-Logo_6mm_SilkScreen
C1 | 1 | CC0603KRX5R5BB475 | Main:CAPC0603 |  | Yageo | CC0603KRX5R5BB475 | GENERIC |  | ±10% |  | 4.70 µF | 6.3V | X5R
C14 | 1 | CL21A475KLCLQNC | Main:CAPC0805 |  | Samsung Electro-Mechanics America, Inc. | CL21A475KLCLQNC | GENERIC |  | ±10% |  | 4.70 µF | 35V | X5R
C15 C16 C24 | 3 | CC0603KRX7R9BB103 | Main:CAPC0603 |  | Yageo | CC0603KRX7R9BB103 | GENERIC |  | ±10% |  | 10.0 nF | 50.0V | X7R
C17 | 1 | CC0603KRX7R9BB682 | Main:CAPC0603 |  | Yageo | CC0603KRX7R9BB682 | GENERIC |  | ±10% |  | 6.80 nF | 50.0V | X7R
C12 C18 | 2 | CC0603JRNPO9BN180 | Main:CAPC0603 |  | Yageo | CC0603JRNPO9BN180 | GENERIC |  | ±5% |  | 18.0 pF | 50.0V | C0G/NP0
C2 C20 C21 C3 | 4 | CC0805MKX5R5BB226 | Main:CAPC0805 |  | Yageo | CC0805MKX5R5BB226 | GENERIC |  | ±20% |  | 22.0 µF | 6.3V | X5R
C10 C11 C13 C19 C22 C23 C25 C26 C27 C4 C5 C6 C7 | 13 | CC0603KRX7R9BB104 | Main:CAPC0603 |  | Yageo | CC0603KRX7R9BB104 | GENERIC |  | ±10% |  | 100 nF | 50.0 | X7R
C8 C9 | 2 | CC0603JRNPO9BN120 | Main:CAPC0603 |  | Yageo | CC0603JRNPO9BN120 | GENERIC |  | ±5% |  | 12.0 pF | 50.0V | C0G/NP0
D1 | 1 | LTST-C171GKT | Main:DIOC200X120X110 |  | Lite-On Inc. | LTST-C171GKT | STUFF |  |  |  |  |  |  | GREEN
D2 | 1 | LTST-C171TBKT | Main:DIOC200X120X110 |  | Lite-On Inc. | LTST-C171TBKT | STUFF |  |  |  |  |  |  | BLUE
D5 | 1 | MBR0520LT1G | Main:SOD3717X135 |  | ON Semiconductor | MBR0520LT1G | STUFF
DLED1 DLED2 DLED3 DLED4 | 4 | LTW-170TK | Main:DIOC200X120X110 |  | Lite-On Inc. | LTW-170TK | COMMON |  |  |  |  |  |  | WHITE
DLED5 | 1 | LTST-C171KRKT | Main:DIOC200X120X110 |  | Lite-On Inc. | LTST-C171KRKT | STUFF |  |  |  |  |  |  | RED
FID1 FID2 FID3 | 3 | FIDTOP001 | Main:FIDTOP001
J16 | 1 | CONN127P-02X05 | Main:CONN127P-02X05 |  | Sullins Connector Solutions | GRPB052VWVN-RC | DNI
J17 | 1 | USB_B_RECEPTACLE | Main:USB_B_RECEPTACLE |  | On Shore Technology Inc. | USB-B1HSW6 | GENERIC
J19 | 1 | COMPUTE_MOD_1 | Main:COMPUTE_MOD_1
J20 J31 | 2 | USB_A_RECEPTACLE | Main:USB_A_RECEPTACLE |  | Amphenol Commercial Products | UE27AC54100 | STUFF
J25 | 1 | SOCKET420P-02X04-CPU | Main:SOCKET420P-02X04 |  | TE Connectivity AMP Connectors | 1586042-8 | GENERIC
J1 J10 J11 J12 J13 J14 J15 J2 J3 J4 J5 J6 J7 J8 J9 | 15 | PCIESOCKET-X1 | Main:PCIESOCKET-X1 |  | Amphenol FCI | 10018784-10200TLF | STUFF
J81 J82 | 2 | SOCKET254P-01X02 | Main:SOCKET254P-01X02 |  | TE Connectivity AMP Connectors | 640456-2 | DNI
J18 J83 | 2 | SOCKET254P-01X02 | Main:SOCKET254P-01X02_2 |  | Harwin Inc. | M20-9990246 | GENERIC
L1 | 1 | INDUCTOR_SRN4026-2R2Y | Main:INDP400400X250 |  | Bourns Inc. | SRN4026-2R2Y | STUFF
L2 | 1 | 600Ohms | Main:RESC0603 |  | Wurth Electronics Inc | 742792651 | GENERIC
L3 | 1 | INDUCTOR_SRN6045TA-4R7M | Main:INDP600600X420 |  | Bourns Inc. | SRN6045TA-4R7M | STUFF
MP2 | 1 | BRACKET-R1000AX | Main:BRACKET-R1000AX
MP3 | 1 | MICROSD_DM3AT-SF-PEJM5 | Main:MICROSD_RECEPTACLE_2 |  | Hirose Electric Co Ltd | DM3AT-SF-PEJM5 | STUFF
MP1 MP10 MP11 MP12 MP4 MP5 MP6 MP7 MP8 MP9 | 10 | MECH_NPTH_M3 | Main:MECH_NPTH_M3
Q1 | 1 | DMG2305UX-7 | Main:SOT190P290X130X100-3 |  | Diodes Incorporated | DMG2305UX-7 | STUFF
Q2 | 1 | PSMN1R2-30YLC | Main:SOT127P500X110-5 |  | NXP Semiconductors | PSMN1R2-30YLC,115 | STUFF
Q3 Q5 Q6 | 3 | Q_PNP_BEC | Main:SOT190P290X130X100-3 |  | ON Semiconductor | MMBT4403LT3G | STUFF
Q4 | 1 | Q_NPN_BEC | Main:SOT190P290X130X100-3 |  | ON Semiconductor | MMBT2222ALT3G | STUFF
R1 R2 R3 R4 R5 | 5 | RC0603FR-071KL | Main:RESC0603 |  | Yageo | RC0603FR-071KL | GENERIC | 1.00 kΩ | ±1% | 100 mW
R10 R11 | 2 | RC0603FR-0733R2L | Main:RESC0603 |  | Yageo | RC0603FR-0733R2L | GENERIC | 33.2 Ω | ±1% | 100 mW
R12 | 1 | RC0603FR-071K5L | Main:RESC0603 |  | Yageo | RC0603FR-071K5L | GENERIC | 1.50 kΩ | ±1% | 100 mW
R14 | 1 | RC0603FR-0751K1L | Main:RESC0603 |  | Yageo | RC0603FR-0751K1L | GENERIC | 51.1 kΩ | ±1% | 100 mW
R15 | 1 | RC0603FR-079K76L | Main:RESC0603 |  | Yageo | RC0603FR-079K76L | GENERIC | 9.76 kΩ | ±1% | 100 mW
R16 | 1 | RSENSE_WSL3637 | Main:RESC940914X064 |  | Vishay Dale | WSL36373L000FEA | STUFF
R24 | 1 | RC0603FR-0711KL | Main:RESC0603 |  | Yageo | RC0603FR-0711KL | GENERIC | 11.0 kΩ | ±1% | 100 mW
R25 | 1 | RC0603FR-076K49L | Main:RESC0603 |  | Yageo | RC0603FR-076K49L | GENERIC | 6.49 kΩ | ±1% | 100 mW
R28 R30 | 2 | ERJ-8CWFR030V | Main:RESC1206 |  | Panasonic Electronic Components | ERJ-8CWFR030V | GENERIC | 0.03 Ω | ±1% | 1 W
R29 R31 | 2 | RC0603FR-070RL | Main:RESC0603 |  | Yageo | RC0603FR-070RL | GENERIC | 0.00 Ω | ±1% | 100 mW
R32 R33 R34 R35 R36 R37 | 6 | RC0603FR-077R5L | Main:RESC0603 |  | Yageo | RC0603FR-077R5L | GENERIC | 7.50 Ω | ±1% | 100 mW
R23 R26 R39 R70 | 4 | RC0603FR-0766K5L | Main:RESC0603 |  | Yageo | RC0603FR-0766K5L | GENERIC | 66.5 kΩ | ±1% | 100 mW
R40 R41 R42 R43 | 4 | ERJ-3GEY0R00V | Main:RESC0603 |  | Panasonic Electronic Components | ERJ-3GEY0R00V | DNI | 0.00 Ω | ±1% | 100 mW
R27 R38 R6 | 3 | RC0603FR-072K21L | Main:RESC0603 |  | Yageo | RC0603FR-072K21L | GENERIC | 2.21 kΩ | ±1% | 100 mW
R13 R17 R18 R19 R20 R21 R22 R67 R69 R7 | 10 | RC0603FR-0710KL | Main:RESC0603 |  | Yageo | RC0603FR-0710KL | GENERIC | 10.0 kΩ | ±1% | 100 mW
R8 | 1 | RC0603FR-0727K4L | Main:RESC0603 |  | Yageo | RC0603FR-0727K4L | GENERIC | 27.4 kΩ | ±1% | 100 mW
R9 | 1 | RC0603FR-076K04L | Main:RESC0603 |  | Yageo | RC0603FR-076K04L | GENERIC | 6.04 kΩ | ±1% | 100 mW
S1 S2 S3 | 3 | SPST_PUSHBTN | Main:SPST_PUSHBTN |  | TE Connectivity Alcoswitch Switches | 1825027-5 | STUFF
TP1 | 1 | TestPoint | Main:TestPoint000
U1 | 1 | LPC1769FBD100,551 | Main:QFP50P1400X1400X160-100 |  | NXP Semiconductors | LPC1769FBD100,551 | STUFF
U2 | 1 | AP3418 | Main:SOT095P300X150X145-5 |  | Diodes Incorporated | AP3418KTR-G1 | STUFF
U20 | 1 | M24C08-FDW6TP | Main:SOP65P440X300X120-8 |  | STMicroelectronics | M24C08-FDW6TP | STUFF
U3 | 1 | BD9E302EFJ-E2 | Main:SOP127P490X390X100-8NT320X240 |  | Rohm Semiconductor | BD9E302EFJ-E2 | STUFF
U4 | 1 | INA3221AIRGVR | Main:QFN65P400X400X90-16NT210X210 |  | Texas Instruments | INA3221AIRGVR | STUFF
U5 | 1 | LM5060MM/NOPB | Main:SOP50P300X300X100-10 |  | Texas Instruments | LM5060MM/NOPB | STUFF
Y1 | 1 | XTAL4_12MHz | Main:XTAL320X250X100 |  | Abracon LLC | ABM8G-12.000MHZ-4Y-T3 | STUFF

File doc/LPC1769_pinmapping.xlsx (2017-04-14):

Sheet: LPC1769FBD100,551
Pin Name | LQFP100 Pin | Smoothie Board Reserved? | Reconfigurable? | ADC Input | I2C | SPI | Smoothie Function | Notes
TDO/SWO | 1 | 1 |  |  |  |  | NC-JTAG
TDI | 2 | 1 |  |  |  |  | NC-JTAG
TMS/SWDIO | 3 | 1 |  |  |  |  | NC-JTAG
TRST | 4 | 1 |  |  |  |  | NC-JTAG
TCK/SWDCLK | 5 | 1 |  |  |  |  | NC-JTAG
P0[26]/AD0[3]/AOUT/RXD3 | 6 |  | 1 | 1 |  |  | TH4
P0[25]/AD0[2]/I2SRX_SDA/TXD3 | 7 |  | 1 | 1 |  |  | TH3
P0[24]/AD0[1]/I2SRX_WS/CAP3[1] | 8 |  | 1 | 1 |  |  | TH2
P0[23]/AD0[0]/I2SRX_CLK/CAP3[0] | 9 |  | 1 | 1 |  |  | TH1
VDDA | 10 | 1 |  |  |  |  | 3.3V
VSSA | 11 | 1 |  |  |  |  | GND
VREFP | 12 | 1 |  |  |  |  | 3.3V
n.c. | 13 | 1 |  |  |  |  | NC
RSTOUT | 14 | 1 |  |  |  |  | doesn’t exist in symbol
VREFN | 15 | 1 |  |  |  |  | GND
RTCX1 | 16 | 1 |  |  |  |  | NC
RESET | 17 | 1 |  |  |  |  | Reset button
RTCX2 | 18 | 1 |  |  |  |  | NC
VBAT | 19 | 1 |  |  |  |  | 3.3V
P1[31]/SCK1/AD0[5] | 20 |  | 1 | 1 |  |  | P1_31
P1[30]/VBUS/AD0[4] | 21 |  | 1 | 1 |  |  | P1_30
XTAL1 | 22 | 1 |  |  |  |  | Crystal
XTAL2 | 23 | 1 |  |  |  |  | Crystal
P0[28]/SCL0/USB_SCL | 24 | 1 |  |  |  |  | I2C | Verify firmware
P0[27]/SDA0/USB_SDA | 25 | 1 |  |  |  |  | I2C | Verify firmware
P3[26]/STCLK/MAT0[1]/PWM1[3] | 26 |  | 1 |  |  |  | P3_26
P3[25]/MAT0[0]/PWM1[2] | 27 |  | 1 |  |  |  | P3_25
VDD(3V3) | 28 | 1 |  |  |  |  | 3.3V
P0[29]/USB_D+ | 29 | 1 |  |  |  |  | USB
P0[30]/USB_D | 30 | 1 |  |  |  |  | USB
VSS | 31 | 1 |  |  |  |  | GND
P1[18]/USB_UP_LED/PWM1[1]/CAP1[0] | 32 |  | 1 |  |  |  | LED1
P1[19]/MCOA0/USB_PPWR/CAP1[1] | 33 |  | 1 |  |  |  | LED2
P1[20]/MCI0/PWM1[2]/SCK0 | 34 |  | 1 |  |  |  | LED3
P1[21]/MCABORT/PWM1[3]/SSEL0 | 35 |  | 1 |  |  |  | LED4
P1[22]/MCOB0/USB_PWRD/MAT1[0] | 36 |  | 1 |  |  |  | P1_22
P1[23]/MCI1/PWM1[4]/MISO0 | 37 |  | 1 |  |  | 1 | P1_23
P1[24]/MCI2/PWM1[5]/MOSI0 | 38 |  | 1 |  |  | 1 | X_MIN
P1[25]/MCOA1/MAT1[1] | 39 |  | 1 |  |  |  | X_MAX
P1[26]/MCOB1/PWM1[6]/CAP0[0] | 40 |  | 1 |  |  |  | Y_MIN
VSS | 41 | 1 |  |  |  |  | GND
VDD(REG)(3V3)*** | 42 | 1 |  |  |  |  | 3.3V
P1[27]/CLKOUT/USB_OVRCR/CAP0[1] | 43 |  | 1 |  |  |  | Y_MAX
P1[28]/MCOA2/PCAP1[0]/MAT0[0] | 44 |  | 1 |  |  |  | Z_MIN
P1[29]/MCOB2/PCAP1[1]/MAT0[1] | 45 |  | 1 |  |  |  | Z_MAX
P0[0]/RD1/TXD3/SDA1 | 46 |  | 1 |  | 1 |  | POT_SDA | should be, check firmware option ability
P0[1]/TD1/RXD3/SCL1 | 47 |  | 1 |  | 1 |  | POT_SCL | should be, check firmware option ability
P0[10]/TXD2/SDA2/MAT3[0] | 48 |  | 1 |  | 1 |  | EN2
P0[11]/RXD2/SCL2/MAT3[1] | 49 |  | 1 |  | 1 |  | DIR2
P2[13]/EINT3/I2STX_SDA | 50 |  | 1 |  |  |  | DIR5
P2[12]/EINT2/I2STX_WS | 51 |  | 1 |  |  |  | PLAY/P2_12
P2[11]/EINT1/I2STX_CLK | 52 |  | 1 |  |  |  | P2_11
P2[10]/EINT0/NMI | 53 |  | 1 |  |  |  | ISP_BOOT/P2_10
VDD(3V3) | 54 | 1 |  |  |  |  | 3.3V
VSS | 55 | 1 |  |  |  |  | GND
P0[22]/RTS1/TD1 | 56 |  | 1 |  |  |  | DIR4
P0[21]/RI1/RD1 | 57 |  | 1 |  |  |  | EN4
P0[20]/DTR1/SCL1 | 58 |  | 1 |  | 1 |  | DIR3
P0[19]/DSR1/SDA1 | 59 |  | 1 |  | 1 |  | EN3
P0[18]/DCD1/MOSI0/MOSI | 60 |  | 1 |  |  | 1 | Panel SPI
P0[17]/CTS1/MISO0/MISO | 61 |  | 1 |  |  | 1 | Panel SPI
P0[15]/TXD1/SCK0/SCK | 62 |  | 1 |  |  | 1 | Panel SPI
P0[16]/RXD1/SSEL0/SSEL | 63 |  | 1 |  |  | 1 | Panel SPI
P2[9]/USB_CONNECT/RXD2 | 64 |  | 1 |  |  |  | P2_9
P2[8]/TD2/TXD2 | 65 |  | 1 |  |  |  | STP5
P2[7]/RD2/RTS1 | 66 |  | 1 |  |  |  | P2_7
P2[6]/PCAP1[0]/RI1/TRACECLK | 67 |  | 1 |  |  |  | P2_6
P2[5]/PWM1[6]/DTR1/TRACEDATA[0] | 68 |  | 1 |  |  |  | P2_5
P2[4]/PWM1[5]/DSR1/TRACEDATA[1] | 69 |  | 1 |  |  |  | P2_4
P2[3]/PWM1[4]/DCD1/TRACEDATA[2] | 70 |  | 1 |  |  |  | ST4
VDD(3V3) | 71 | 1 |  |  |  |  | 3.3V
VSS | 72 | 1 |  |  |  |  | GND
P2[2]/PWM1[3]/CTS1/TRACEDATA[3] | 73 |  | 1 |  |  |  | ST3
P2[1]/PWM1[2]/RXD1 | 74 |  | 1 |  |  |  | ST2
P2[0]/PWM1[1]/TXD1 | 75 |  | 1 |  |  |  | ST1
P0[9]/I2STX_SDA/MOSI1/MAT2[3] | 76 | 1 |  |  |  |  | SPI_SD
P0[8]/I2STX_WS/MISO1/MAT2[2] | 77 | 1 |  |  |  |  | SPI_SD
P0[7]/I2STX_CLK/SCK1/MAT2[1] | 78 | 1 |  |  |  |  | SPI_SD
P0[6]/I2SRX_SDA/SSEL1/MAT2[0] | 79 | 1 |  |  |  |  | SPI_SD
P0[5]/I2SRX_WS/TD2/CAP2[1] | 80 |  | 1 |  |  |  | DIR1
P0[4]/I2SRX_CLK/RD2/CAP2[0] | 81 |  | 1 |  |  |  | EN1
P4[28]/RX_MCLK/MAT2[0]/TXD3 | 82 |  | 1 |  |  |  | PLAY_LED
VSS | 83 | 1 |  |  |  |  | GND
VDD(REG)(3V3) | 84 | 1 |  |  |  |  | 3.3V
P4[29]/TX_MCLK/MAT2[1]/RXD3 | 85 |  | 1 |  |  |  | EN5
P1[17]/ENET_MDIO | 86 | 1 |  |  |  |  | Ethernet
P1[16]/ENET_MDC | 87 | 1 |  |  |  |  | Ethernet
P1[15]/ENET_REF_CLK | 88 | 1 |  |  |  |  | Ethernet
P1[14]/ENET_RX_ER | 89 | 1 |  |  |  |  | Ethernet
P1[10]/ENET_RXD1 | 90 | 1 |  |  |  |  | Ethernet
P1[9]/ENET_RXD0 | 91 | 1 |  |  |  |  | Ethernet
P1[8]/ENET_CRS | 92 | 1 |  |  |  |  | Ethernet
P1[4]/ENET_TX_EN | 93 | 1 |  |  |  |  | Ethernet
P1[1]/ENET_TXD1 | 94 | 1 |  |  |  |  | Ethernet
P1[0]/ENET_TXD0 | 95 | 1 |  |  |  |  | Ethernet
VDD(3V3) | 96 | 1 |  |  |  |  | 3.3V
VSS | 97 | 1 |  |  |  |  | GND
P0[2]/TXD0/AD0[7] | 98 |  | 1 | 1 |  |  | TX_0 | not sure
P0[3]/RXD0/AD0[6] | 99 |  | 1 | 1 |  |  | RX_0 | not sure
RTCK | 100 | 1 |  |  |  |  | NC

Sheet: V1.0
Pin Name | LQFP100 Pin | Smoothie Board Reserved? | Reconfigurable? | ADC Input | I2C | SPI | Smoothie Function | F1 | F2 | F3 | F4 | PEX Group | PEX Func | Net Name
TDO/SWO | 1 | 1 |  |  |  |  | NC-JTAG | TDO | SWO
TDI | 2 | 1 |  |  |  |  | NC-JTAG | TDI
TMS/SWDIO | 3 | 1 |  |  |  |  | NC-JTAG | TMS | SWDIO
TRST | 4 | 1 |  |  |  |  | NC-JTAG | TRST
TCK/SWDCLK | 5 | 1 |  |  |  |  | NC-JTAG | TCK | SWDCLK
P0[26]/AD0[3]/AOUT/RXD3 | 6 |  | 1 | 1 |  |  | TH4 | P0[26] | AD0[3] | AOUT | RXD3 | 1.13 | ADC/UART | J02.PX3.A14
P0[25]/AD0[2]/I2SRX_SDA/TXD3 | 7 |  | 1 | 1 |  |  | TH3 | P0[25] | AD0[2] |  | TXD3 | 1.14 | ADC/UART | J02.PX4.A15
P0[24]/AD0[1]/I2SRX_WS/CAP3[1] | 8 |  | 1 | 1 |  |  | TH2 | P0[24] | AD0[1] |  |  | 1.12 | ADC/UART | J02.PX2.A13
P0[23]/AD0[0]/I2SRX_CLK/CAP3[0] | 9 |  | 1 | 1 |  |  | TH1 | P0[23] | AD0[0] |  |  | 1.11 | ADC/UART | J02.PX1.A12
VDDA | 10 | 1 |  |  |  |  | 3.3V | VDDA
VSSA | 11 | 1 |  |  |  |  | GND | VSSA
VREFP | 12 | 1 |  |  |  |  | 3.3V | VREFP
n.c. | 13 | 1 |  |  |  |  | NC | n.c.
RSTOUT | 14 | 1 |  |  |  |  | NC | RSTOUT
VREFN | 15 | 1 |  |  |  |  | GND | VREFN
RTCX1 | 16 | 1 |  |  |  |  | NC | RTCX1
RESET | 17 | 1 |  |  |  |  | Reset button | RESET
RTCX2 | 18 | 1 |  |  |  |  | NC | RTCX2
VBAT | 19 | 1 |  |  |  |  | 3.3V | VBAT
P1[31]/SCK1/AD0[5] | 20 |  | 1 | 1 |  |  | P1_31 | P1[31] | SCK1 | AD0[5] |  | 1.21 | ADC/UART | J03.PX1.A12
P1[30]/VBUS/AD0[4] | 21 |  | 1 | 1 |  |  | P1_30 | P1[30] | VBUS | AD0[4] |  | 1.22 | ADC/UART | J03.PX2.A13
XTAL1 | 22 | 1 |  |  |  |  | Crystal | XTAL1
XTAL2 | 23 | 1 |  |  |  |  | Crystal | XTAL2
P0[28]/SCL0/USB_SCL | 24 | 1 |  |  |  |  | I2C | P0[28] | SCL0 | USB_SCL
P0[27]/SDA0/USB_SDA | 25 | 1 |  |  |  |  | I2C | P0[27] | SDA0 | USB_SDA
P3[26]/STCLK/MAT0[1]/PWM1[3] | 26 |  | 1 |  |  |  | P3_26 | P3[26] |  |  |  | 5.21 | GPIO | J12.PX1.A12
P3[25]/MAT0[0]/PWM1[2] | 27 |  | 1 |  |  |  | P3_25 | P3[25] |  |  |  | 5.22 | GPIO | J12.PX2.A13
VDD(3V3) | 28 | 1 |  |  |  |  | 3.3V | VDD(3V3)
P0[29]/USB_D+ | 29 | 1 |  |  |  |  | USB | P0[29] | USB_D+
P0[30]/USB_D | 30 | 1 |  |  |  |  | USB | P0[30] | USB_D
VSS | 31 | 1 |  |  |  |  | GND | VSS
P1[18]/USB_UP_LED/PWM1[1]/CAP1[0] | 32 |  | 1 |  |  |  | LED1 | P1[18] |  | PWM1[1] |  | 3.11 | PWM | J08.PX1.A12
P1[19]/MCOA0/USB_PPWR/CAP1[1] | 33 |  | 1 |  |  |  | LED2 | P1[19] |  |  |  | 5.23 | GPIO | J12.PX3.A14
P1[20]/MCI0/PWM1[2]/SCK0 | 34 |  | 1 |  |  |  | LED3 | P1[20] |  | PWM1[2] |  | 3.12 | PWM | J08.PX2.A13
P1[21]/MCABORT/PWM1[3]/SSEL0 | 35 |  | 1 |  |  |  | LED4 | P1[21] |  |  |  | 5.24 | GPIO | J12.PX4.A15
P1[22]/MCOB0/USB_PWRD/MAT1[0] | 36 |  | 1 |  |  |  | P1_22 | P1[22] |  |  |  | 5.31 | GPIO | J13.PX1.A12
P1[23]/MCI1/PWM1[4]/MISO0 | 37 |  | 1 |  |  | 1 | P1_23 | P1[23] |  |  |  | 5.32 | GPIO | J13.PX2.A13
P1[24]/MCI2/PWM1[5]/MOSI0 | 38 |  | 1 |  |  | 1 | X_MIN | P1[24] |  |  |  | 5.33 | GPIO | J13.PX3.A14
P1[25]/MCOA1/MAT1[1] | 39 |  | 1 |  |  |  | X_MAX | P1[25] |  |  |  | 5.34 | GPIO | J13.PX4.A15
P1[26]/MCOB1/PWM1[6]/CAP0[0] | 40 |  | 1 |  |  |  | Y_MIN | P1[26] |  |  |  | 5.41 | GPIO | J14.PX1.A12
VSS | 41 | 1 |  |  |  |  | GND | VSS
VDDREG3V3 | 42 | 1 |  |  |  |  | 3.3V | VDDREG3V3
P1[27]/CLKOUT/USB_OVRCR/CAP0[1] | 43 |  | 1 |  |  |  | Y_MAX | P1[27] |  |  |  | 5.42 | GPIO | J14.PX2.A13
P1[28]/MCOA2/PCAP1[0]/MAT0[0] | 44 |  | 1 |  |  |  | Z_MIN | P1[28] |  |  |  | 5.43 | GPIO | J14.PX3.A14
P1[29]/MCOB2/PCAP1[1]/MAT0[1] | 45 |  | 1 |  |  |  | Z_MAX | P1[29] |  |  |  | 5.44 | GPIO | J14.PX4.A15
P0[0]/RD1/TXD3/SDA1 | 46 |  | 1 |  | 1 |  | POT_SDA | P0[0] |  |  |  | 4.21 | I2C | J10.PX1.A12
P0[1]/TD1/RXD3/SCL1 | 47 |  | 1 |  | 1 |  | POT_SCL | P0[1] |  |  |  | 4.22 | I2C | J10.PX2.A13
P0[10]/TXD2/SDA2/MAT3[0] | 48 |  | 1 |  | 1 |  | EN2 | P0[10] | TXD2 | SDA2 |  | 4.24 | I2C | J10.PX4.A15
P0[11]/RXD2/SCL2/MAT3[1] | 49 |  | 1 |  | 1 |  | DIR2 | P0[11] | RXD2 | SCL2 |  | 4.23 | I2C | J10.PX3.A14
P2[13]/EINT3/I2STX_SDA | 50 |  | 1 |  |  |  | DIR5 | P2[13] |  |  |  | 5.11 | GPIO | J11.PX1.A12
P2[12]/EINT2/I2STX_WS | 51 |  | 1 |  |  |  | PLAY/P2_12 | P2[12] |  |  |  | 5.12 | GPIO | J11.PX2.A13
P2[11]/EINT1/I2STX_CLK | 52 |  | 1 |  |  |  | P2_11 | P2[11] |  |  |  | 5.13 | GPIO | J11.PX3.A14
P2[10]/EINT0/NMI | 53 |  | 1 |  |  |  | ISP_BOOT/P2_10 | P2[10] |  |  |  | 5.14 | GPIO | J11.PX4.A15
VDD(3V3) | 54 | 1 |  |  |  |  | 3.3V | VDD(3V3)
VSS | 55 | 1 |  |  |  |  | GND | VSS
P0[22]/RTS1/TD1 | 56 |  | 1 |  |  |  | DIR4 | P0[22] |  |  |  | 4.11 | I2C/CAN | J09.PX1.A12
P0[21]/RI1/RD1 | 57 |  | 1 |  |  |  | EN4 | P0[21] |  |  |  | 4.12 | I2C/CAN | J09.PX2.A13
P0[20]/DTR1/SCL1 | 58 |  | 1 |  | 1 |  | DIR3 | P0[20] |  | SCL1 |  | 4.13 | I2C/CAN | J09.PX3.A14
P0[19]/DSR1/SDA1 | 59 |  | 1 |  | 1 |  | EN3 | P0[19] |  | SDA1 |  | 4.14 | I2C/CAN | J09.PX4.A15
P0[18]/DCD1/MOSI0/MOSI | 60 |  | 1 |  |  | 1 | Panel SPI | P0[18] |  | MOSI0 |  | 2.11 | SPI0 | J07.PX1.A12
P0[17]/CTS1/MISO0/MISO | 61 |  | 1 |  |  | 1 | Panel SPI | P0[17] |  | MISO0 |  | 2.12 | SPI0 | J07.PX2.A13
P0[15]/TXD1/SCK0/SCK | 62 |  | 1 |  |  | 1 | Panel SPI | P0[15] |  | SCK0 |  | 2.13 | SPI0 | J07.PX4.A15
P0[16]/RXD1/SSEL0/SSEL | 63 |  | 1 |  |  | 1 | Panel SPI | P0[16] |  | SSEL0 | SSEL | 2.14 | SPI0 | J07.PX3.A14
P2[9]/USB_CONNECT/RXD2 | 64 |  | 1 |  |  |  | P2_9 | P2[9] |  | RXD2 |  | 1.33 | UART | J04.PX3.A14 | Dedicated to USB connect
P2[8]/TD2/TXD2 | 65 |  | 1 |  |  |  | STP5 | P2[8] |  | TXD2 |  | 1.34 | UART | J04.PX4.A15
P2[7]/RD2/RTS1 | 66 |  | 1 |  |  |  | P2_7 | P2[7] |  |  |  | 1.31 | UART | J04.PX1.A12
P2[6]/PCAP1[0]/RI1/TRACECLK | 67 |  | 1 |  |  |  | P2_6 | P2[6] |  |  |  | 1.32 | UART | J04.PX2.A13
P2[5]/PWM1[6]/DTR1/TRACEDATA[0] | 68 |  | 1 |  |  |  | P2_5 | P2[5] | PWM1[6] |  |  | 3.13 | PWM | J08.PX3.A14
P2[4]/PWM1[5]/DSR1/TRACEDATA[1] | 69 |  | 1 |  |  |  | P2_4 | P2[4] | PWM1[5] |  |  | 3.14 | PWM | J08.PX4.A15
P2[3]/PWM1[4]/DCD1/TRACEDATA[2] | 70 |  | 1 |  |  |  | ST4 | P2[3] | PWM1[4] |  |  | 1.41 | UART/PWM | J05.PX1.A12
VDD(3V3) | 71 | 1 |  |  |  |  | 3.3V | VDD(3V3)
VSS | 72 | 1 |  |  |  |  | GND | VSS
P2[2]/PWM1[3]/CTS1/TRACEDATA[3] | 73 |  | 1 |  |  |  | ST3 | P2[2] | PWM1[3] |  |  | 1.42 | UART/PWM | J05.PX2.A13
P2[1]/PWM1[2]/RXD1 | 74 |  | 1 |  |  |  | ST2 | P2[1] | PWM1[2] | RXD1 |  | 1.43 | UART/PWM | J05.PX3.A14
P2[0]/PWM1[1]/TXD1 | 75 |  | 1 |  |  |  | ST1 | P2[0] | PWM1[1] | TXD1 |  | 1.44 | UART/PWM | J05.PX4.A15
P0[9]/I2STX_SDA/MOSI1/MAT2[3] | 76 | 1 |  |  |  |  | SPI_SD | P0[9] | I2STX_SDA | MOSI1 | MAT2[3] | 0.11 | SPI1 | J01.PX1.A12
P0[8]/I2STX_WS/MISO1/MAT2[2] | 77 | 1 |  |  |  |  | SPI_SD | P0[8] | I2STX_WS | MISO1 | MAT2[2] | 0.12 | SPI1 | J01.PX2.A13
P0[7]/I2STX_CLK/SCK1/MAT2[1] | 78 | 1 |  |  |  |  | SPI_SD | P0[7] | I2STX_CLK | SCK1 | MAT2[1] | 0.13 | SPI1 | J01.PX4.A15
P0[6]/I2SRX_SDA/SSEL1/MAT2[0] | 79 | 1 |  |  |  |  | SPI_SD | P0[6] | I2SRX_SDA | SSEL1 | MAT2[0] | 0.14 | SPI1 | J01.PX3.A14
P0[5]/I2SRX_WS/TD2/CAP2[1] | 80 |  | 1 |  |  |  | DIR1 | P0[5] |  |  |  | 1.52 | UART/CAN | J06.PX2.A13
P0[4]/I2SRX_CLK/RD2/CAP2[0] | 81 |  | 1 |  |  |  | EN1 | P0[4] |  |  |  | 1.51 | UART/CAN | J06.PX1.A12
P4[28]/RX_MCLK/MAT2[0]/TXD3 | 82 |  | 1 |  |  |  | PLAY_LED | P4[28] |  |  | TXD3 | 1.54 | UART/CAN | J06.PX4.A15
VSS | 83 | 1 |  |  |  |  | GND | VSS
VDD(REG)(3V3) | 84 | 1 |  |  |  |  | 3.3V | VDD(REG)(3V3)
P4[29]/TX_MCLK/MAT2[1]/RXD3 | 85 |  | 1 |  |  |  | EN5 | P4[29] |  |  | RXD3 | 1.53 | UART/CAN | J06.PX3.A14
P1[17]/ENET_MDIO | 86 | 1 |  |  |  |  | Ethernet | P1[17] | ENET_MDIO |  |  | 6.11 | GPIO | J15.PX1.A12
P1[16]/ENET_MDC | 87 | 1 |  |  |  |  | Ethernet | P1[16] | ENET_MDC |  |  | 6.12 | GPIO | J15.PX2.A13
P1[15]/ENET_REF_CLK | 88 | 1 |  |  |  |  | Ethernet | P1[15] | ENET_REF_CLK |  |  | 6.13 | GPIO | J15.PX3.A14
P1[14]/ENET_RX_ER | 89 | 1 |  |  |  |  | Ethernet | P1[14] | ENET_RX_ER |  |  | 6.14 | GPIO | J15.PX4.A15
P1[10]/ENET_RXD1 | 90 | 1 |  |  |  |  | Ethernet | P1[10] | ENET_RXD1 |  |  | 6.21 | GPIO | J16.PX1.A12
P1[9]/ENET_RXD0 | 91 | 1 |  |  |  |  | Ethernet | P1[9] | ENET_RXD0 |  |  | 6.22 | GPIO | J16.PX2.A13
P1[8]/ENET_CRS | 92 | 1 |  |  |  |  | Ethernet | P1[8] | ENET_CRS |  |  | 6.23 | GPIO | J16.PX3.A14
P1[4]/ENET_TX_EN | 93 | 1 |  |  |  |  | Ethernet | P1[4] | ENET_TX_EN |  |  | 6.24 | GPIO | J16.PX4.A15
P1[1]/ENET_TXD1 | 94 | 1 |  |  |  |  | Ethernet | P1[1] | ENET_TXD1
P1[0]/ENET_TXD0 | 95 | 1 |  |  |  |  | Ethernet | P1[0] | ENET_TXD0
VDD(3V3) | 96 | 1 |  |  |  |  | 3.3V | VDD(3V3)
VSS | 97 | 1 |  |  |  |  | GND | VSS
P0[2]/TXD0/AD0[7] | 98 |  | 1 | 1 |  |  | TX_0 | P0[2] | TXD0 | AD0[7] |  | 1.24 | ADC/UART | J03.PX4.A15
P0[3]/RXD0/AD0[6] | 99 |  | 1 | 1 |  |  | RX_0 | P0[3] | RXD0 | AD0[6] |  | 1.23 | ADC/UART | J03.PX3.A14
RTCK | 100 | 1 |  |  |  |  | NC | RTCK

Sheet: V1.1
Pin Name | LQFP100 Pin | Smoothie Board Reserved? | Reconfigurable? | ADC Input | I2C | SPI | Smoothie Function | F1 | F2 | F3 | F4 |  |  |  |  |  |  | UART | I2C | SPI
P0[26]/AD0[3]/AOUT/RXD3 | 6 |  | 1 | 1 |  |  | TH4 | P0[26] | AD0[3] | AOUT | RXD3 |  | J8 | X2 | A13 | P0[26] | X1 |  |  | MOSI
P0[25]/AD0[2]/I2SRX_SDA/TXD3 | 7 |  | 1 | 1 |  |  | TH3 | P0[25] | AD0[2] |  | TXD3 |  |  | X1 | A12 | P0[25] | X2 |  |  | MISO
P0[24]/AD0[1]/I2SRX_WS/CAP3[1] | 8 |  | 1 | 1 |  |  | TH2 | P0[24] | AD0[1] |  |  |  | J1 | X1 | A12 | P0[24] | X3 | RX | SCL | SSEL
P0[23]/AD0[0]/I2SRX_CLK/CAP3[0] | 9 |  | 1 | 1 |  |  | TH1 | P0[23] | AD0[0] |  |  |  |  | X2 | A13 | P0[23] | X4 | TX | SDA | SCK
P1[31]/SCK1/AD0[5] | 20 |  | 1 | 1 |  |  | P1_31 | P1[31] | SCK1 | AD0[5] |  |  |  | X3 | A14 | P1[31]
P1[30]/VBUS/AD0[4] | 21 |  | 1 | 1 |  |  | P1_30 | P1[30] | VBUS | AD0[4] |  |  |  | X4 | A15 | P1[30]
P0[28]/SCL0/USB_SCL | 24 | 1 |  |  |  |  | I2C | P0[28] | Reserved SCL0
P0[27]/SDA0/USB_SDA | 25 | 1 |  |  |  |  | I2C | P0[27] | Reserved SDA0
P3[26]/STCLK/MAT0[1]/PWM1[3] | 26 |  | 1 |  |  |  | P3_26 | P3[26] |  |  |  |  | J13 | X2 | A13 | P3[26]
P3[25]/MAT0[0]/PWM1[2] | 27 |  | 1 |  |  |  | P3_25 | P3[25] |  |  |  | May be MRESET? |  | MRESET
P0[29]/USB_D+ | 29 | 1 |  |  |  |  | USB | P0[29] | Reserved USB_D+
P0[30]/USB_D | 30 | 1 |  |  |  |  | USB | P0[30] | Reserved USB_D
P1[18]/USB_UP_LED/PWM1[1]/CAP1[0] | 32 |  | 1 |  |  |  | LED1 | P1[18] |  |  |  | J_LED | J11 | X4 | A15 | P1[18]
P1[19]/MCOA0/USB_PPWR/CAP1[1] | 33 |  | 1 |  |  |  | LED2 | P1[19] |  |  |  |  |  | X3 | A14 | P1[19]
P1[20]/MCI0/PWM1[2]/SCK0 | 34 |  | 1 |  |  |  | LED3 | P1[20] |  |  |  |  |  | X2 | A13 | P1[20]
P1[21]/MCABORT/PWM1[3]/SSEL0 | 35 |  | 1 |  |  |  | LED4 | P1[21] |  |  |  |  |  | X1 | A12 | P1[21]
P1[22]/MCOB0/USB_PWRD/MAT1[0] | 36 |  | 1 |  |  |  | P1_22 | P1[22] |  |  |  | J_GPIO | J3 | X4 | A15 | P1[22]
P1[23]/MCI1/PWM1[4]/MISO0 | 37 |  | 1 |  |  | 1 | P1_23 | P1[23] |  |  |  |  |  | X3 | A14 | P1[23]
P1[24]/MCI2/PWM1[5]/MOSI0 | 38 |  | 1 |  |  | 1 | X_MIN | P1[24] |  |  |  |  |  | X2 | A13 | P1[24]
P1[25]/MCOA1/MAT1[1] | 39 |  | 1 |  |  |  | X_MAX | P1[25] |  |  |  |  |  | X1 | A12 | P1[25]
P1[26]/MCOB1/PWM1[6]/CAP0[0] | 40 |  | 1 |  |  |  | Y_MIN | P1[26] |  |  |  | J_GPIO | J4 | X4 | A15 | P1[26]
P1[27]/CLKOUT/USB_OVRCR/CAP0[1] | 43 |  | 1 |  |  |  | Y_MAX | P1[27] |  |  |  |  |  | X3 | A14 | P1[27]
P1[28]/MCOA2/PCAP1[0]/MAT0[0] | 44 |  | 1 |  |  |  | Z_MIN | P1[28] |  |  |  |  |  | X2 | A13 | P1[28]
P1[29]/MCOB2/PCAP1[1]/MAT0[1] | 45 |  | 1 |  |  |  | Z_MAX | P1[29] |  |  |  |  |  | X1 | A12 | P1[29]
P0[0]/RD1/TXD3/SDA1 | 46 |  | 1 |  | 1 |  | POT_SDA | P0[0] |  |  |  | J_UART2/I2C2 | J5 | X1 | A12 | P0[0]
P0[1]/TD1/RXD3/SCL1 | 47 |  | 1 |  | 1 |  | POT_SCL | P0[1] |  |  |  |  |  | X2 | A13 | P0[1]
P0[10]/TXD2/SDA2/MAT3[0] | 48 |  | 1 |  | 1 |  | EN2 | P0[10] | TXD2 | SDA2 |  |  |  | X4 | A15 | P0[10]
P0[11]/RXD2/SCL2/MAT3[1] | 49 |  | 1 |  | 1 |  | DIR2 | P0[11] | RXD2 | SCL2 |  |  |  | X3 | A14 | P0[11]
P2[13]/EINT3/I2STX_SDA | 50 |  | 1 |  |  |  | DIR5 | P2[13] |  |  |  |  | J6 | X1 | A12 | P2[13]
P2[12]/EINT2/I2STX_WS | 51 |  | 1 |  |  |  | PLAY/P2_12 | P2[12] |  |  |  |  |  | X2 | A13 | P2[12]
P2[11]/EINT1/I2STX_CLK | 52 |  | 1 |  |  |  | P2_11 | P2[11] |  |  |  |  |  | X3 | A14 | P2[11]
P2[10]/EINT0/NMI | 53 |  | 1 |  |  |  | ISP_BOOT/P2_10 | P2[10] | ISP_BOOT |  |  |  |  | X4 | A15 | P2[10]
P0[22]/RTS1/TD1 | 56 |  | 1 |  |  |  | DIR4 | P0[22] |  |  |  |  | J7 | X1 | A12 | P0[22]
P0[21]/RI1/RD1 | 57 |  | 1 |  |  |  | EN4 | P0[21] |  |  |  |  |  | X2 | A13 | P0[21]
P0[20]/DTR1/SCL1 | 58 |  | 1 |  | 1 |  | DIR3 | P0[20] |  | SCL1 |  |  |  | X3 | A14 | P0[20]
P0[19]/DSR1/SDA1 | 59 |  | 1 |  | 1 |  | EN3 | P0[19] |  | SDA1 |  |  |  | X4 | A15 | P0[19]
P0[18]/DCD1/MOSI0/MOSI | 60 |  | 1 |  |  | 1 | Panel SPI | P0[18] |  | MOSI0 |  |  | J9 | X1 | A12 | P0[18]
P0[17]/CTS1/MISO0/MISO | 61 |  | 1 |  |  | 1 | Panel SPI | P0[17] |  | MISO0 |  |  |  | X2 | A13 | P0[17]
P0[15]/TXD1/SCK0/SCK | 62 |  | 1 |  |  | 1 | Panel SPI | P0[15] |  | SCK0 |  |  |  | X4 | A15 | P0[15]
P0[16]/RXD1/SSEL0/SSEL | 63 |  | 1 |  |  | 1 | Panel SPI | P0[16] |  | SSEL0 | SSEL |  |  | X3 | A14 | P0[16]
P2[9]/USB_CONNECT/RXD2 | 64 | 1 |  |  |  |  | P2_9 | P2[9] | Reserved, USB P-drive
P2[8]/TD2/TXD2 | 65 |  | 1 |  |  |  | STP5 | P2[8] |  |  |  |  | J13 | X1 | A12 | P2[8]
P2[7]/RD2/RTS1 | 66 |  | 1 |  |  |  | P2_7 | P2[7] |  |  |  |  | J10 | X1 | A12 | P2[7]
P2[6]/PCAP1[0]/RI1/TRACECLK | 67 |  | 1 |  |  |  | P2_6 | P2[6] |  |  |  |  |  | X2 | A13 | P2[6]
P2[5]/PWM1[6]/DTR1/TRACEDATA[0] | 68 |  | 1 |  |  |  | P2_5 | P2[5] | PWM1[6] |  |  |  |  | X3 | A14 | P2[5]
P2[4]/PWM1[5]/DSR1/TRACEDATA[1] | 69 |  | 1 |  |  |  | P2_4 | P2[4] | PWM1[5] |  |  |  |  | X4 | A15 | P2[4]
P2[3]/PWM1[4]/DCD1/TRACEDATA[2] | 70 |  | 1 |  |  |  | ST4 | P2[3] | PWM1[4] |  |  |  | J2 | X1 | A12 | P2[3]
P2[2]/PWM1[3]/CTS1/TRACEDATA[3] | 73 |  | 1 |  |  |  | ST3 | P2[2] | PWM1[3] |  |  |  |  | X2 | A13 | P2[2]
P2[1]/PWM1[2]/RXD1 | 74 |  | 1 |  |  |  | ST2 | P2[1] | PWM1[2] | RXD1 |  |  |  | X3 | A14 | P2[1]
P2[0]/PWM1[1]/TXD1 | 75 |  | 1 |  |  |  | ST1 | P2[0] | PWM1[1] | TXD1 |  |  |  | X4 | A15 | P2[0]
P0[9]/I2STX_SDA/MOSI1/MAT2[3] | 76 | 1 |  |  |  |  | SPI_SD | P0[9] | Reserved SDC MOSI1
P0[8]/I2STX_WS/MISO1/MAT2[2] | 77 | 1 |  |  |  |  | SPI_SD | P0[8] | Reserved SDC MISO1
P0[7]/I2STX_CLK/SCK1/MAT2[1] | 78 | 1 |  |  |  |  | SPI_SD | P0[7] | Reserved SDC SCK1
P0[6]/I2SRX_SDA/SSEL1/MAT2[0] | 79 | 1 |  |  |  |  | SPI_SD | P0[6] | Reserved SDC SSEL1
P0[5]/I2SRX_WS/TD2/CAP2[1] | 80 |  | 1 |  |  |  | DIR1 | P0[5] |  |  |  |  | J12 | X1 | A12 | P0[5]
P0[4]/I2SRX_CLK/RD2/CAP2[0] | 81 |  | 1 |  |  |  | EN1 | P0[4] |  |  |  |  |  | X2 | A13 | P0[4]
P4[28]/RX_MCLK/MAT2[0]/TXD3 | 82 |  | 1 |  |  |  | PLAY_LED | P4[28] |  |  | TXD3 |  |  | X4 | A15 | P4[28]
P4[29]/TX_MCLK/MAT2[1]/RXD3 | 85 |  | 1 |  |  |  | EN5 | P4[29] |  |  | RXD3 |  |  | X3 | A14 | P4[29]
P1[17]/ENET_MDIO | 86 | 1 |  |  |  |  | Ethernet | P1[17] | ENET_MDIO |  |  |  | J14 | X1 | A12 | P1[17]
P1[16]/ENET_MDC | 87 | 1 |  |  |  |  | Ethernet | P1[16] | ENET_MDC |  |  |  |  | X2 | A13 | P1[16]
P1[15]/ENET_REF_CLK | 88 | 1 |  |  |  |  | Ethernet | P1[15] | ENET_REF_CLK |  |  |  |  | X3 | A14 | P1[15]
P1[14]/ENET_RX_ER | 89 | 1 |  |  |  |  | Ethernet | P1[14] | ENET_RX_ER |  |  |  |  | X4 | A15 | P1[14]
P1[10]/ENET_RXD1 | 90 | 1 |  |  |  |  | Ethernet | P1[10] | ENET_RXD1 |  |  |  | J15 | X1 | A12 | P1[10]
P1[9]/ENET_RXD0 | 91 | 1 |  |  |  |  | Ethernet | P1[9] | ENET_RXD0 |  |  |  |  | X2 | A13 | P1[9]
P1[8]/ENET_CRS | 92 | 1 |  |  |  |  | Ethernet | P1[8] | ENET_CRS |  |  |  |  | X3 | A14 | P1[8]
P1[4]/ENET_TX_EN | 93 | 1 |  |  |  |  | Ethernet | P1[4] | ENET_TX_EN |  |  |  |  | X4 | A15 | P1[4]
P1[1]/ENET_TXD1 | 94 | 1 |  |  |  |  | Ethernet | P1[1] | ENET_TXD1 |  |  |  | J13 | X4 | A15 | P1[1]
P1[0]/ENET_TXD0 | 95 | 1 |  |  |  |  | Ethernet | P1[0] | ENET_TXD0 |  |  |  | J13 | X3 | A14 | P1[0]
P0[2]/TXD0/AD0[7] | 98 |  | 1 | 1 |  |  | TX_0 | P0[2] | TXD0 | AD0[7] |  | J_ADC2 | J8 | X4 | A15 | P0[2]
P0[3]/RXD0/AD0[6] | 99 |  | 1 | 1 |  |  | RX_0 | P0[3] | RXD0 | AD0[6] |  |  |  | X3 | A14 | P0[3]

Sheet: V1.2
Pin Name | LQFP100 Pin | Smoothie Board Reserved? | Reconfigurable? | ADC Input | I2C | SPI | Smoothie Function | F1 | F2 | F3 | F4 | Juicy Function | JNAME | XNAME | ANAME | Port |  | UART | I2C | SPI
P0[28]/SCL0/USB_SCL | 24 | 1 |  |  |  |  | I2C | P0[28] | Reserved SCL0 |  |  |  | I2C0 |  |  |  | X1 |  |  | MOSI
P0[27]/SDA0/USB_SDA | 25 | 1 |  |  |  |  | I2C | P0[27] | Reserved SDA0 |  |  |  | I2C0 |  |  |  | X2 |  |  | MISO
P0[24]/AD0[1]/I2SRX_WS/CAP3[1] | 8 |  | 1 | 1 |  |  | TH2 | P0[24] | AD0[1] |  |  | ADC | J01 | X1 | A12 | P0[24] | X3 | RX | SCL | SSEL
P0[23]/AD0[0]/I2SRX_CLK/CAP3[0] | 9 |  | 1 | 1 |  |  | TH1 | P0[23] | AD0[0] |  |  | ADC | J01 | X2 | A13 | P0[23] | X4 | TX | SDA | SCK
P1[31]/SCK1/AD0[5] | 20 |  | 1 | 1 |  |  | P1_31 | P1[31] | SCK1 | AD0[5] |  | ADC | J01 | X3 | A14 | P1[31]
P1[30]/VBUS/AD0[4] | 21 |  | 1 | 1 |  |  | P1_30 | P1[30] | VBUS | AD0[4] |  | ADC | J01 | X4 | A15 | P1[30]
P2[3]/PWM1[4]/DCD1/TRACEDATA[2] | 70 |  | 1 |  |  |  | ST4 | P2[3] | PWM1[4] |  |  | PWM | J02 | X1 | A12 | P2[3]
P2[2]/PWM1[3]/CTS1/TRACEDATA[3] | 73 |  | 1 |  |  |  | ST3 | P2[2] | PWM1[3] |  |  | PWM | J02 | X2 | A13 | P2[2]
P2[1]/PWM1[2]/RXD1 | 74 |  | 1 |  |  |  | ST2 | P2[1] | PWM1[2] | RXD1 |  | PWM | J02 | X3 | A14 | P2[1]
P2[0]/PWM1[1]/TXD1 | 75 |  | 1 |  |  |  | ST1 | P2[0] | PWM1[1] | TXD1 |  | PWM | J02 | X4 | A15 | P2[0]
P1[25]/MCOA1/MAT1[1] | 39 |  | 1 |  |  |  | X_MAX | P1[25] |  |  |  | GPIO | J03 | X1 | A12 | P1[25]
P1[24]/MCI2/PWM1[5]/MOSI0 | 38 |  | 1 |  |  | 1 | X_MIN | P1[24] |  |  |  | GPIO | J03 | X2 | A13 | P1[24]
P1[23]/MCI1/PWM1[4]/MISO0 | 37 |  | 1 |  |  | 1 | P1_23 | P1[23] |  |  |  | GPIO | J03 | X3 | A14 | P1[23]
P1[22]/MCOB0/USB_PWRD/MAT1[0] | 36 |  | 1 |  |  |  | P1_22 | P1[22] |  |  |  | GPIO | J03 | X4 | A15 | P1[22]
P1[29]/MCOB2/PCAP1[1]/MAT0[1] | 45 |  | 1 |  |  |  | Z_MAX | P1[29] |  |  |  | GPIO | J04 | X1 | A12 | P1[29]
P1[28]/MCOA2/PCAP1[0]/MAT0[0] | 44 |  | 1 |  |  |  | Z_MIN | P1[28] |  |  |  | GPIO | J04 | X2 | A13 | P1[28]
P1[27]/CLKOUT/USB_OVRCR/CAP0[1] | 43 |  | 1 |  |  |  | Y_MAX | P1[27] |  |  |  | GPIO | J04 | X3 | A14 | P1[27]
P1[26]/MCOB1/PWM1[6]/CAP0[0] | 40 |  | 1 |  |  |  | Y_MIN | P1[26] |  |  |  | GPIO | J04 | X4 | A15 | P1[26]
P0[0]/RD1/TXD3/SDA1 | 46 |  | 1 |  | 1 |  | POT_SDA | P0[0] |  |  |  | UART2/I2C2 | J05 | X1 | A12 | P0[0]
P0[1]/TD1/RXD3/SCL1 | 47 |  | 1 |  | 1 |  | POT_SCL | P0[1] |  |  |  | UART2/I2C2 | J05 | X2 | A13 | P0[1]
P0[11]/RXD2/SCL2/MAT3[1] | 49 |  | 1 |  | 1 |  | DIR2 | P0[11] | RXD2 | SCL2 |  | UART2/I2C2 | J05 | X3 | A14 | P0[11]
P0[10]/TXD2/SDA2/MAT3[0] | 48 |  | 1 |  | 1 |  | EN2 | P0[10] | TXD2 | SDA2 |  | UART2/I2C2 | J05 | X4 | A15 | P0[10]
P2[13]/EINT3/I2STX_SDA | 50 |  | 1 |  |  |  | DIR5 | P2[13] |  |  |  | GPIO | J06 | X1 | A12 | P2[13]
P2[12]/EINT2/I2STX_WS | 51 |  | 1 |  |  |  | PLAY/P2_12 | P2[12] |  |  |  | GPIO | J06 | X2 | A13 | P2[12]
P2[11]/EINT1/I2STX_CLK | 52 |  | 1 |  |  |  | P2_11 | P2[11] |  |  |  | GPIO | J06 | X3 | A14 | P2[11]
P3[25]/MAT0[0]/PWM1[2] | 27 |  | 1 |  |  |  | P3_25 | P3[25] |  |  |  | GPIO | J06 | X4 | A15 | P3[25]
P0[22]/RTS1/TD1 | 56 |  | 1 |  |  |  | DIR4 | P0[22] |  |  |  | I2C1 | J07 | X1 | A12 | P0[22]
P0[21]/RI1/RD1 | 57 |  | 1 |  |  |  | EN4 | P0[21] |  |  |  | I2C1 | J07 | X2 | A13 | P0[21]
P0[20]/DTR1/SCL1 | 58 |  | 1 |  | 1 |  | DIR3 | P0[20] |  | SCL1 |  | I2C1 | J07 | X3 | A14 | P0[20]
P0[19]/DSR1/SDA1 | 59 |  | 1 |  | 1 |  | EN3 | P0[19] |  | SDA1 |  | I2C1 | J07 | X4 | A15 | P0[19]
P0[25]/AD0[2]/I2SRX_SDA/TXD3 | 7 |  | 1 | 1 |  |  | TH3 | P0[25] | AD0[2] |  | TXD3 | ADC/UART0 | J08 | X1 | A12 | P0[25]
P0[26]/AD0[3]/AOUT/RXD3 | 6 |  | 1 | 1 |  |  | TH4 | P0[26] | AD0[3] | AOUT | RXD3 | ADC/UART0 | J08 | X2 | A13 | P0[26]
P0[3]/RXD0/AD0[6] | 99 |  | 1 | 1 |  |  | RX_0 | P0[3] | RXD0 | AD0[6] |  | ADC/UART0 | J08 | X3 | A14 | P0[3]
P0[2]/TXD0/AD0[7] | 98 |  | 1 | 1 |  |  | TX_0 | P0[2] | TXD0 | AD0[7] |  | ADC/UART0 | J08 | X4 | A15 | P0[2]
P0[18]/DCD1/MOSI0/MOSI | 60 |  | 1 |  |  | 1 | Panel SPI | P0[18] |  | MOSI0 |  | SPI0 | J09 | X1 | A12 | P0[18]
P0[17]/CTS1/MISO0/MISO | 61 |  | 1 |  |  | 1 | Panel SPI | P0[17] |  | MISO0 |  | SPI0 | J09 | X2 | A13 | P0[17]
P0[16]/RXD1/SSEL0/SSEL | 63 |  | 1 |  |  | 1 | Panel SPI | P0[16] |  | SSEL0 | SSEL | SPI0 | J09 | X3 | A14 | P0[16]
P0[15]/TXD1/SCK0/SCK | 62 |  | 1 |  |  | 1 | Panel SPI | P0[15] |  | SCK0 |  | SPI0 | J09 | X4 | A15 | P0[15]
P2[7]/RD2/RTS1 | 66 |  | 1 |  |  |  | P2_7 | P2[7] |  |  |  | GPIO | J10 | X1 | A12 | P2[7]
P2[6]/PCAP1[0]/RI1/TRACECLK | 67 |  | 1 |  |  |  | P2_6 | P2[6] |  |  |  | GPIO | J10 | X2 | A13 | P2[6]
P2[5]/PWM1[6]/DTR1/TRACEDATA[0] | 68 |  | 1 |  |  |  | P2_5 | P2[5] | PWM1[6] |  |  | GPIO | J10 | X3 | A14 | P2[5]
P2[4]/PWM1[5]/DSR1/TRACEDATA[1] | 69 |  | 1 |  |  |  | P2_4 | P2[4] | PWM1[5] |  |  | GPIO | J10 | X4 | A15 | P2[4]
P1[21]/MCABORT/PWM1[3]/SSEL0 | 35 |  | 1 |  |  |  | LED4 | P1[21] |  |  |  | LED/GPIO | J11 | X1 | A12 | P1[21]
P1[20]/MCI0/PWM1[2]/SCK0 | 34 |  | 1 |  |  |  | LED3 | P1[20] |  |  |  | LED/GPIO | J11 | X2 | A13 | P1[20]
P1[19]/MCOA0/USB_PPWR/CAP1[1] | 33 |  | 1 |  |  |  | LED2 | P1[19] |  |  |  | LED/GPIO | J11 | X3 | A14 | P1[19]
P1[18]/USB_UP_LED/PWM1[1]/CAP1[0] | 32 |  | 1 |  |  |  | LED1 | P1[18] |  |  |  | LED/GPIO | J11 | X4 | A15 | P1[18]
P0[5]/I2SRX_WS/TD2/CAP2[1] | 80 |  | 1 |  |  |  | DIR1 | P0[5] |  |  |  | UART3 | J12 | X1 | A12 | P0[5]
P0[4]/I2SRX_CLK/RD2/CAP2[0] | 81 |  | 1 |  |  |  | EN1 | P0[4] |  |  |  | UART3 | J12 | X2 | A13 | P0[4]
P4[29]/TX_MCLK/MAT2[1]/RXD3 | 85 |  | 1 |  |  |  | EN5 | P4[29] |  |  | RXD3 | UART3 | J12 | X3 | A14 | P4[29]
P4[28]/RX_MCLK/MAT2[0]/TXD3 | 82 |  | 1 |  |  |  | PLAY_LED | P4[28] |  |  | TXD3 | UART3 | J12 | X4 | A15 | P4[28]
P2[8]/TD2/TXD2 | 65 |  | 1 |  |  |  | STP5 | P2[8] |  |  |  | ENET0 | J13 | X1 | A12 | P2[8]
P3[26]/STCLK/MAT0[1]/PWM1[3] | 26 |  | 1 |  |  |  | P3_26 | P3[26] |  |  |  | ENET0 | J13 | X2 | A13 | P3[26]
P1[0]/ENET_TXD0 | 95 | 1 |  |  |  |  | Ethernet | P1[0] | ENET_TXD0 |  |  | ENET0 | J13 | X3 | A14 | P1[0]
P1[1]/ENET_TXD1 | 94 | 1 |  |  |  |  | Ethernet | P1[1] | ENET_TXD1 |  |  | ENET0 | J13 | X4 | A15 | P1[1]
P1[17]/ENET_MDIO | 86 | 1 |  |  |  |  | Ethernet | P1[17] | ENET_MDIO |  |  | ENET1 | J14 | X1 | A12 | P1[17]
P1[16]/ENET_MDC | 87 | 1 |  |  |  |  | Ethernet | P1[16] | ENET_MDC |  |  | ENET1 | J14 | X2 | A13 | P1[16]
P1[15]/ENET_REF_CLK | 88 | 1 |  |  |  |  | Ethernet | P1[15] | ENET_REF_CLK |  |  | ENET1 | J14 | X3 | A14 | P1[15]
P1[14]/ENET_RX_ER | 89 | 1 |  |  |  |  | Ethernet | P1[14] | ENET_RX_ER |  |  | ENET1 | J14 | X4 | A15 | P1[14]
P1[10]/ENET_RXD1 | 90 | 1 |  |  |  |  | Ethernet | P1[10] | ENET_RXD1 |  |  | ENET2 | J15 | X1 | A12 | P1[10]
P1[9]/ENET_RXD0 | 91 | 1 |  |  |  |  | Ethernet | P1[9] | ENET_RXD0 |  |  | ENET2 | J15 | X2 | A13 | P1[9]
P1[8]/ENET_CRS | 92 | 1 |  |  |  |  | Ethernet | P1[8] | ENET_CRS |  |  | ENET2 | J15 | X3 | A14 | P1[8]
P1[4]/ENET_TX_EN | 93 | 1 |  |  |  |  | Ethernet | P1[4] | ENET_TX_EN |  |  | ENET2 | J15 | X4 | A15 | P1[4]
P2[10]/EINT0/NMI | 53 |  | 1 |  |  |  | ISP_BOOT/P2_10 | P2[10] | ISP_BOOT |  |  | ISP/MRESET | MRESET
P0[9]/I2STX_SDA/MOSI1/MAT2[3] | 76 | 1 |  |  |  |  | SPI_SD | P0[9] | Reserved SDC MOSI1 |  |  |  | SD
P0[8]/I2STX_WS/MISO1/MAT2[2] | 77 | 1 |  |  |  |  | SPI_SD | P0[8] | Reserved SDC MISO1 |  |  |  | SD
P0[7]/I2STX_CLK/SCK1/MAT2[1] | 78 | 1 |  |  |  |  | SPI_SD | P0[7] | Reserved SDC SCK1 |  |  |  | SD
P0[6]/I2SRX_SDA/SSEL1/MAT2[0] | 79 | 1 |  |  |  |  | SPI_SD | P0[6] | Reserved SDC SSEL1 |  |  |  | SD
P0[29]/USB_D+ | 29 | 1 |  |  |  |  | USB | P0[29] | Reserved USB_D+ |  |  |  | USB
P0[30]/USB_D | 30 | 1 |  |  |  |  | USB | P0[30] | Reserved USB_D |  |  |  | USB
P2[9]/USB_CONNECT/RXD2 | 64 | 1 |  |  |  |  | P2_9 | P2[9] | Reserved, USB P-drive |  |  |  | USB DFU P
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

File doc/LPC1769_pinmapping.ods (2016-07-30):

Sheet: LPC1769FBD100,551
Pin Name | LQFP100 Pin | Smoothie Board Reserved? | Reconfigurable? | ADC Input | I2C | SPI | Smoothie Function | Notes
TDO/SWO | 1 | 1 |  |  |  |  | NC-JTAG
TDI | 2 | 1 |  |  |  |  | NC-JTAG
TMS/SWDIO | 3 | 1 |  |  |  |  | NC-JTAG
TRST | 4 | 1 |  |  |  |  | NC-JTAG
TCK/SWDCLK | 5 | 1 |  |  |  |  | NC-JTAG
P0[26]/AD0[3]/AOUT/RXD3 | 6 |  | 1 | 1 |  |  | TH4
P0[25]/AD0[2]/I2SRX_SDA/TXD3 | 7 |  | 1 | 1 |  |  | TH3
P0[24]/AD0[1]/I2SRX_WS/CAP3[1] | 8 |  | 1 | 1 |  |  | TH2
P0[23]/AD0[0]/I2SRX_CLK/CAP3[0] | 9 |  | 1 | 1 |  |  | TH1
VDDA | 10 | 1 |  |  |  |  | 3.3V
VSSA | 11 | 1 |  |  |  |  | GND
VREFP | 12 | 1 |  |  |  |  | 3.3V
n.c. | 13 | 1 |  |  |  |  | NC
RSTOUT | 14 | 1 |  |  |  |  | doesn’t exist in symbol
VREFN | 15 | 1 |  |  |  |  | GND
RTCX1 | 16 | 1 |  |  |  |  | NC
RESET | 17 | 1 |  |  |  |  | Reset button
RTCX2 | 18 | 1 |  |  |  |  | NC
VBAT | 19 | 1 |  |  |  |  | 3.3V
P1[31]/SCK1/AD0[5] | 20 |  | 1 | 1 |  |  | P1_31
P1[30]/VBUS/AD0[4] | 21 |  | 1 | 1 |  |  | P1_30
XTAL1 | 22 | 1 |  |  |  |  | Crystal
XTAL2 | 23 | 1 |  |  |  |  | Crystal
P0[28]/SCL0/USB_SCL | 24 | 1 |  |  |  |  | I2C | Verify firmware
P0[27]/SDA0/USB_SDA | 25 | 1 |  |  |  |  | I2C | Verify firmware
P3[26]/STCLK/MAT0[1]/PWM1[3] | 26 |  | 1 |  |  |  | P3_26
P3[25]/MAT0[0]/PWM1[2] | 27 |  | 1 |  |  |  | P3_25
VDD(3V3) | 28 | 1 |  |  |  |  | 3.3V
P0[29]/USB_D+ | 29 | 1 |  |  |  |  | USB
P0[30]/USB_D | 30 | 1 |  |  |  |  | USB
VSS | 31 | 1 |  |  |  |  | GND
P1[18]/USB_UP_LED/PWM1[1]/CAP1[0] | 32 |  | 1 |  |  |  | LED1
P1[19]/MCOA0/USB_PPWR/CAP1[1] | 33 |  | 1 |  |  |  | LED2
P1[20]/MCI0/PWM1[2]/SCK0 | 34 |  | 1 |  |  |  | LED3
P1[21]/MCABORT/PWM1[3]/SSEL0 | 35 |  | 1 |  |  |  | LED4
P1[22]/MCOB0/USB_PWRD/MAT1[0] | 36 |  | 1 |  |  |  | P1_22
P1[23]/MCI1/PWM1[4]/MISO0 | 37 |  | 1 |  |  | 1 | P1_23
P1[24]/MCI2/PWM1[5]/MOSI0 | 38 |  | 1 |  |  | 1 | X_MIN
P1[25]/MCOA1/MAT1[1] | 39 |  | 1 |  |  |  | X_MAX
P1[26]/MCOB1/PWM1[6]/CAP0[0] | 40 |  | 1 |  |  |  | Y_MIN
VSS | 41 | 1 |  |  |  |  | GND
VDD(REG)(3V3)*** | 42 | 1 |  |  |  |  | 3.3V
P1[27]/CLKOUT/USB_OVRCR/CAP0[1] | 43 |  | 1 |  |  |  | Y_MAX
P1[28]/MCOA2/PCAP1[0]/MAT0[0] | 44 |  | 1 |  |  |  | Z_MIN
P1[29]/MCOB2/PCAP1[1]/MAT0[1] | 45 |  | 1 |  |  |  | Z_MAX
P0[0]/RD1/TXD3/SDA1 | 46 |  | 1 |  | 1 |  | POT_SDA | should be, check firmware option ability
P0[1]/TD1/RXD3/SCL1 | 47 |  | 1 |  | 1 |  | POT_SCL | should be, check firmware option ability
P0[10]/TXD2/SDA2/MAT3[0] | 48 |  | 1 |  | 1 |  | EN2
P0[11]/RXD2/SCL2/MAT3[1] | 49 |  | 1 |  | 1 |  | DIR2
P2[13]/EINT3/I2STX_SDA | 50 |  | 1 |  |  |  | DIR5
P2[12]/EINT2/I2STX_WS | 51 |  | 1 |  |  |  | PLAY/P2_12
P2[11]/EINT1/I2STX_CLK | 52 |  | 1 |  |  |  | P2_11
P2[10]/EINT0/NMI | 53 |  | 1 |  |  |  | ISP_BOOT/P2_10
VDD(3V3) | 54 | 1 |  |  |  |  | 3.3V
VSS | 55 | 1 |  |  |  |  | GND
P0[22]/RTS1/TD1 | 56 |  | 1 |  |  |  | DIR4
P0[21]/RI1/RD1 | 57 |  | 1 |  |  |  | EN4
P0[20]/DTR1/SCL1 | 58 |  | 1 |  | 1 |  | DIR3
P0[19]/DSR1/SDA1 | 59 |  | 1 |  | 1 |  | EN3
P0[18]/DCD1/MOSI0/MOSI | 60 |  | 1 |  |  | 1 | Panel SPI
P0[17]/CTS1/MISO0/MISO | 61 |  | 1 |  |  | 1 | Panel SPI
P0[15]/TXD1/SCK0/SCK | 62 |  | 1 |  |  | 1 | Panel SPI
P0[16]/RXD1/SSEL0/SSEL | 63 |  | 1 |  |  | 1 | Panel SPI
P2[9]/USB_CONNECT/RXD2 | 64 |  | 1 |  |  |  | P2_9
P2[8]/TD2/TXD2 | 65 |  | 1 |  |  |  | STP5
P2[7]/RD2/RTS1 | 66 |  | 1 |  |  |  | P2_7
P2[6]/PCAP1[0]/RI1/TRACECLK | 67 |  | 1 |  |  |  | P2_6
P2[5]/PWM1[6]/DTR1/TRACEDATA[0] | 68 |  | 1 |  |  |  | P2_5
P2[4]/PWM1[5]/DSR1/TRACEDATA[1] | 69 |  | 1 |  |  |  | P2_4
P2[3]/PWM1[4]/DCD1/TRACEDATA[2] | 70 |  | 1 |  |  |  | ST4
VDD(3V3) | 71 | 1 |  |  |  |  | 3.3V
VSS | 72 | 1 |  |  |  |  | GND
P2[2]/PWM1[3]/CTS1/TRACEDATA[3] | 73 |  | 1 |  |  |  | ST3
P2[1]/PWM1[2]/RXD1 | 74 |  | 1 |  |  |  | ST2
P2[0]/PWM1[1]/TXD1 | 75 |  | 1 |  |  |  | ST1
P0[9]/I2STX_SDA/MOSI1/MAT2[3] | 76 | 1 |  |  |  |  | SPI_SD
P0[8]/I2STX_WS/MISO1/MAT2[2] | 77 | 1 |  |  |  |  | SPI_SD
P0[7]/I2STX_CLK/SCK1/MAT2[1] | 78 | 1 |  |  |  |  | SPI_SD
P0[6]/I2SRX_SDA/SSEL1/MAT2[0] | 79 | 1 |  |  |  |  | SPI_SD
P0[5]/I2SRX_WS/TD2/CAP2[1] | 80 |  | 1 |  |  |  | DIR1
P0[4]/I2SRX_CLK/RD2/CAP2[0] | 81 |  | 1 |  |  |  | EN1
P4[28]/RX_MCLK/MAT2[0]/TXD3 | 82 |  | 1 |  |  |  | PLAY_LED
VSS | 83 | 1 |  |  |  |  | GND
VDD(REG)(3V3) | 84 | 1 |  |  |  |  | 3.3V
P4[29]/TX_MCLK/MAT2[1]/RXD3 | 85 |  | 1 |  |  |  | EN5
P1[17]/ENET_MDIO | 86 | 1 |  |  |  |  | Ethernet
P1[16]/ENET_MDC | 87 | 1 |  |  |  |  | Ethernet
P1[15]/ENET_REF_CLK | 88 | 1 |  |  |  |  | Ethernet
P1[14]/ENET_RX_ER | 89 | 1 |  |  |  |  | Ethernet
P1[10]/ENET_RXD1 | 90 | 1 |  |  |  |  | Ethernet
P1[9]/ENET_RXD0 | 91 | 1 |  |  |  |  | Ethernet
P1[8]/ENET_CRS | 92 | 1 |  |  |  |  | Ethernet
P1[4]/ENET_TX_EN | 93 | 1 |  |  |  |  | Ethernet
P1[1]/ENET_TXD1 | 94 | 1 |  |  |  |  | Ethernet
P1[0]/ENET_TXD0 | 95 | 1 |  |  |  |  | Ethernet
VDD(3V3) | 96 | 1 |  |  |  |  | 3.3V
VSS | 97 | 1 |  |  |  |  | GND
P0[2]/TXD0/AD0[7] | 98 |  | 1 | 1 |  |  | TX_0 | not sure
P0[3]/RXD0/AD0[6] | 99 |  | 1 | 1 |  |  | RX_0 | not sure
RTCK | 100 | 1 |  |  |  |  | NC

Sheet: Processed
Pin Name | LQFP100 Pin | Smoothie Board Reserved? | Reconfigurable? | ADC Input | I2C | SPI | Smoothie Function | F1 | F2 | F3 | F4 | PEX Group | Func | Net Name | Sch Check
P0[9]/I2STX_SDA/MOSI1/MAT2[3] | 76 | 1 |  |  |  |  | SPI_SD | P0[9] | I2STX_SDA | MOSI1 | MAT2[3] | 0.11 | SPI1 | J01.PX1.A12 | /
P0[8]/I2STX_WS/MISO1/MAT2[2] | 77 | 1 |  |  |  |  | SPI_SD | P0[8] | I2STX_WS | MISO1 | MAT2[2] | 0.12 | SPI1 | J01.PX2.A13 | /
P0[6]/I2SRX_SDA/SSEL1/MAT2[0] | 79 | 1 |  |  |  |  | SPI_SD | P0[6] | I2SRX_SDA | SSEL1 | MAT2[0] | 0.14 | SPI1 | J01.PX3.A14 | /
P0[7]/I2STX_CLK/SCK1/MAT2[1] | 78 | 1 |  |  |  |  | SPI_SD | P0[7] | I2STX_CLK | SCK1 | MAT2[1] | 0.13 | SPI1 | J01.PX4.A15 | /
P0[23]/AD0[0]/I2SRX_CLK/CAP3[0] | 9 |  | 1 | 1 |  |  | TH1 | P0[23] | AD0[0] |  |  | 1.11 | ADC/UART | J02.PX1.A12 | /
P0[24]/AD0[1]/I2SRX_WS/CAP3[1] | 8 |  | 1 | 1 |  |  | TH2 | P0[24] | AD0[1] |  |  | 1.12 | ADC/UART | J02.PX2.A13 | /
P0[26]/AD0[3]/AOUT/RXD3 | 6 |  | 1 | 1 |  |  | TH4 | P0[26] | AD0[3] | AOUT | RXD3 | 1.13 | ADC/UART | J02.PX3.A14 | /
P0[25]/AD0[2]/I2SRX_SDA/TXD3 | 7 |  | 1 | 1 |  |  | TH3 | P0[25] | AD0[2] |  | TXD3 | 1.14 | ADC/UART | J02.PX4.A15 | /
P1[31]/SCK1/AD0[5] | 20 |  | 1 | 1 |  |  | P1_31 | P1[31] | SCK1 | AD0[5] |  | 1.21 | ADC/UART | J03.PX1.A12 | /
P1[30]/VBUS/AD0[4] | 21 |  | 1 | 1 |  |  | P1_30 | P1[30] | VBUS | AD0[4] |  | 1.22 | ADC/UART | J03.PX2.A13 | /
P0[3]/RXD0/AD0[6] | 99 |  | 1 | 1 |  |  | RX_0 | P0[3] | RXD0 | AD0[6] |  | 1.23 | ADC/UART | J03.PX3.A14 | /
P0[2]/TXD0/AD0[7] | 98 |  | 1 | 1 |  |  | TX_0 | P0[2] | TXD0 | AD0[7] |  | 1.24 | ADC/UART | J03.PX4.A15 | /
P2[7]/RD2/RTS1 | 66 |  | 1 |  |  |  | P2_7 | P2[7] |  |  |  | 1.31 | GPIO | J04.PX1.A12 | /
P2[6]/PCAP1[0]/RI1/TRACECLK | 67 |  | 1 |  |  |  | P2_6 | P2[6] |  |  |  | 1.32 | GPIO | J04.PX2.A13 | /
P1[1]/ENET_TXD1 | 94 | 1 |  |  |  |  | Ethernet | P1[1] | ENET_TXD1 |  |  | 1.33 | GPIO | J04.PX3.A14 | /
P2[8]/TD2/TXD2 | 65 |  | 1 |  |  |  | STP5 | P2[8] |  | TXD2 |  | 1.34 | GPIO | J04.PX4.A15 | /
P2[3]/PWM1[4]/DCD1/TRACEDATA[2] | 70 |  | 1 |  |  |  | ST4 | P2[3] | PWM1[4] |  |  | 1.41 | UART/PWM | J05.PX1.A12 | /
P2[2]/PWM1[3]/CTS1/TRACEDATA[3] | 73 |  | 1 |  |  |  | ST3 | P2[2] | PWM1[3] |  |  | 1.42 | UART/PWM | J05.PX2.A13 | /
P2[1]/PWM1[2]/RXD1 | 74 |  | 1 |  |  |  | ST2 | P2[1] | PWM1[2] | RXD1 |  | 1.43 | UART/PWM | J05.PX3.A14 | /
P2[0]/PWM1[1]/TXD1 | 75 |  | 1 |  |  |  | ST1 | P2[0] | PWM1[1] | TXD1 |  | 1.44 | UART/PWM | J05.PX4.A15 | /
P0[4]/I2SRX_CLK/RD2/CAP2[0] | 81 |  | 1 |  |  |  | EN1 | P0[4] |  |  |  | 1.51 | UART/CAN | J06.PX1.A12 | /
P0[5]/I2SRX_WS/TD2/CAP2[1] | 80 |  | 1 |  |  |  | DIR1 | P0[5] |  |  |  | 1.52 | UART/CAN | J06.PX2.A13 | /
P4[29]/TX_MCLK/MAT2[1]/RXD3 | 85 |  | 1 |  |  |  | EN5 | P4[29] |  |  | RXD3 | 1.53 | UART/CAN | J06.PX3.A14 | /
P4[28]/RX_MCLK/MAT2[0]/TXD3 | 82 |  | 1 |  |  |  | PLAY_LED | P4[28] |  |  | TXD3 | 1.54 | UART/CAN | J06.PX4.A15 | /
P0[18]/DCD1/MOSI0/MOSI | 60 |  | 1 |  |  | 1 | Panel SPI | P0[18] |  | MOSI0 |  | 2.11 | SPI0 | J07.PX1.A12 | /
P0[17]/CTS1/MISO0/MISO | 61 |  | 1 |  |  | 1 | Panel SPI | P0[17] |  | MISO0 |  | 2.12 | SPI0 | J07.PX2.A13 | /
P0[16]/RXD1/SSEL0/SSEL | 63 |  | 1 |  |  | 1 | Panel SPI | P0[16] |  | SSEL0 | SSEL | 2.14 | SPI0 | J07.PX3.A14 | /
P0[15]/TXD1/SCK0/SCK | 62 |  | 1 |  |  | 1 | Panel SPI | P0[15] |  | SCK0 |  | 2.13 | SPI0 | J07.PX4.A15 | /
P1[18]/USB_UP_LED/PWM1[1]/CAP1[0] | 32 |  | 1 |  |  |  | LED1 | P1[18] |  | PWM1[1] |  | 3.11 | PWM | J08.PX1.A12 | /
P1[20]/MCI0/PWM1[2]/SCK0 | 34 |  | 1 |  |  |  | LED3 | P1[20] |  | PWM1[2] |  | 3.12 | PWM | J08.PX2.A13 | /
P2[5]/PWM1[6]/DTR1/TRACEDATA[0] | 68 |  | 1 |  |  |  | P2_5 | P2[5] | PWM1[6] |  |  | 3.13 | PWM | J08.PX3.A14 | /
P2[4]/PWM1[5]/DSR1/TRACEDATA[1] | 69 |  | 1 |  |  |  | P2_4 | P2[4] | PWM1[5] |  |  | 3.14 | PWM | J08.PX4.A15 | /
P0[22]/RTS1/TD1 | 56 |  | 1 |  |  |  | DIR4 | P0[22] |  |  |  | 4.11 | I2C/CAN | J09.PX1.A12 | /
P0[21]/RI1/RD1 | 57 |  | 1 |  |  |  | EN4 | P0[21] |  |  |  | 4.12 | I2C/CAN | J09.PX2.A13 | /
P0[20]/DTR1/SCL1 | 58 |  | 1 |  | 1 |  | DIR3 | P0[20] |  | SCL1 |  | 4.13 | I2C/CAN | J09.PX3.A14 | /
P0[19]/DSR1/SDA1 | 59 |  | 1 |  | 1 |  | EN3 | P0[19] |  | SDA1 |  | 4.14 | I2C/CAN | J09.PX4.A15 | /
P0[0]/RD1/TXD3/SDA1 | 46 |  | 1 |  | 1 |  | POT_SDA | P0[0] |  |  |  | 4.21 | I2C | J10.PX1.A12 | /
P0[1]/TD1/RXD3/SCL1 | 47 |  | 1 |  | 1 |  | POT_SCL | P0[1] |  |  |  | 4.22 | I2C | J10.PX2.A13 | /
P0[11]/RXD2/SCL2/MAT3[1] | 49 |  | 1 |  | 1 |  | DIR2 | P0[11] | RXD2 | SCL2 |  | 4.23 | I2C | J10.PX3.A14 | /
P0[10]/TXD2/SDA2/MAT3[0] | 48 |  | 1 |  | 1 |  | EN2 | P0[10] | TXD2 | SDA2 |  | 4.24 | I2C | J10.PX4.A15 | /
P2[13]/EINT3/I2STX_SDA | 50 |  | 1 |  |  |  | DIR5 | P2[13] |  |  |  | 5.11 | GPIO | J11.PX1.A12 | /
P2[12]/EINT2/I2STX_WS | 51 |  | 1 |  |  |  | PLAY/P2_12 | P2[12] |  |  |  | 5.12 | GPIO | J11.PX2.A13 | /
P2[11]/EINT1/I2STX_CLK | 52 |  | 1 |  |  |  | P2_11 | P2[11] |  |  |  | 5.13 | GPIO | J11.PX3.A14 | /
P2[10]/EINT0/NMI | 53 |  | 1 |  |  |  | ISP_BOOT/P2_10 | P2[10] |  |  |  | 5.14 | GPIO | J11.PX4.A15 | /
P3[26]/STCLK/MAT0[1]/PWM1[3] | 26 |  | 1 |  |  |  | P3_26 | P3[26] |  |  |  | 5.21 | GPIO | J12.PX1.A12 | /
P3[25]/MAT0[0]/PWM1[2] | 27 |  | 1 |  |  |  | P3_25 | P3[25] |  |  |  | 5.22 | GPIO | J12.PX2.A13 | /
P1[19]/MCOA0/USB_PPWR/CAP1[1] | 33 |  | 1 |  |  |  | LED2 | P1[19] |  |  |  | 5.23 | GPIO | J12.PX3.A14 | /
P1[21]/MCABORT/PWM1[3]/SSEL0 | 35 |  | 1 |  |  |  | LED4 | P1[21] |  |  |  | 5.24 | GPIO | J12.PX4.A15 | /
P1[22]/MCOB0/USB_PWRD/MAT1[0] | 36 |  | 1 |  |  |  | P1_22 | P1[22] |  |  |  | 5.31 | GPIO | J13.PX1.A12 | /
P1[23]/MCI1/PWM1[4]/MISO0 | 37 |  | 1 |  |  | 1 | P1_23 | P1[23] |  |  |  | 5.32 | GPIO | J13.PX2.A13 | /
P1[24]/MCI2/PWM1[5]/MOSI0 | 38 |  | 1 |  |  | 1 | X_MIN | P1[24] |  |  |  | 5.33 | GPIO | J13.PX3.A14 | /
P1[25]/MCOA1/MAT1[1] | 39 |  | 1 |  |  |  | X_MAX | P1[25] |  |  |  | 5.34 | GPIO | J13.PX4.A15 | /
P1[26]/MCOB1/PWM1[6]/CAP0[0] | 40 |  | 1 |  |  |  | Y_MIN | P1[26] |  |  |  | 5.41 | GPIO | J14.PX1.A12 | /
P1[27]/CLKOUT/USB_OVRCR/CAP0[1] | 43 |  | 1 |  |  |  | Y_MAX | P1[27] |  |  |  | 5.42 | GPIO | J14.PX2.A13 | /
P1[28]/MCOA2/PCAP1[0]/MAT0[0] | 44 |  | 1 |  |  |  | Z_MIN | P1[28] |  |  |  | 5.43 | GPIO | J14.PX3.A14 | /
P1[29]/MCOB2/PCAP1[1]/MAT0[1] | 45 |  | 1 |  |  |  | Z_MAX | P1[29] |  |  |  | 5.44 | GPIO | J14.PX4.A15 | /
P1[17]/ENET_MDIO | 86 | 1 |  |  |  |  | Ethernet | P1[17] | ENET_MDIO |  |  | 6.11 | GPIO | J15.PX1.A12 | /
P1[16]/ENET_MDC | 87 | 1 |  |  |  |  | Ethernet | P1[16] | ENET_MDC |  |  | 6.12 | GPIO | J15.PX2.A13 | /
P1[15]/ENET_REF_CLK | 88 | 1 |  |  |  |  | Ethernet | P1[15] | ENET_REF_CLK |  |  | 6.13 | GPIO | J15.PX3.A14 | /
P1[14]/ENET_RX_ER | 89 | 1 |  |  |  |  | Ethernet | P1[14] | ENET_RX_ER |  |  | 6.14 | GPIO | J15.PX4.A15 | /
P1[10]/ENET_RXD1 | 90 | 1 |  |  |  |  | Ethernet | P1[10] | ENET_RXD1 |  |  | 6.21 | GPIO | J16.PX1.A12 | /
P1[9]/ENET_RXD0 | 91 | 1 |  |  |  |  | Ethernet | P1[9] | ENET_RXD0 |  |  | 6.22 | GPIO | J16.PX2.A13 | /
P1[8]/ENET_CRS | 92 | 1 |  |  |  |  | Ethernet | P1[8] | ENET_CRS |  |  | 6.23 | GPIO | J16.PX3.A14 | /
P1[4]/ENET_TX_EN | 93 | 1 |  |  |  |  | Ethernet | P1[4] | ENET_TX_EN |  |  | 6.24 | GPIO | J16.PX4.A15 | /
P2[9]/USB_CONNECT/RXD2 | 64 |  | 1 |  |  |  | P2_9 | P2[9] |  | RXD2 |  |  | UART |  | /
TDO/SWO | 1 | 1 |  |  |  |  | NC-JTAG | TDO | SWO
TDI | 2 | 1 |  |  |  |  | NC-JTAG | TDI
TMS/SWDIO | 3 | 1 |  |  |  |  | NC-JTAG | TMS | SWDIO
TRST | 4 | 1 |  |  |  |  | NC-JTAG | TRST
TCK/SWDCLK | 5 | 1 |  |  |  |  | NC-JTAG | TCK | SWDCLK
VDDA | 10 | 1 |  |  |  |  | 3.3V | VDDA
VSSA | 11 | 1 |  |  |  |  | GND | VSSA
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

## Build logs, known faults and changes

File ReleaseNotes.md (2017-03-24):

# v1.3 (first public release)
- Updated fiducials
- Fixed diode silk-screen and confirmed polarity of every symbol
- Fixed J1 connector I2C address to 0000 (connected address pins to ground)
- Fixed EEPROM #WC to default HIGH (write protected), user can now enable write by shorting TP1 to ground of placing a jumper J18
- Corrected power monitor filter RC values
- Reverted 5V buck input to HT, now low voltage domains are protected by the switch
- Corrected FAULT! LED to light when system shuts down
- Finalized silk screen art

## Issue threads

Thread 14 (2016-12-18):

v1.3 Features

pluggee, 2016-12-18:
- ~~Share high power paths at the bottom of the board between power and ground
  at the moment the HV power occupies 4 layers, make 2 for ground and 2 for HT~~
- Add proper silk screen and markings

pluggee, 2017-02-06:
- Set C23 (Timer cap) = 10x C24 (NFET Gate Cap)
- Remove HT LED (redundant), rename FAULT to Power Good
- Replace power good LED with a green LED
- Replace 3.3V LED with a Blue one (or depending on voltage, maybe it's better to put the blue LED on the HT not 3.3V)

pluggee, 2017-02-06:
- revert input power to 5V buck to output of FET, in a shutdown event 5V will also be shut down, if there's a need to protect data in such events an aux power can be provided through the USB port
- tweak lm5060 resistors to adjust boundary levels

pluggee, 2017-02-06:
- set fault red LED as fault, use blue/green LEDs for HT and low voltage
- consequently remove the option jumper for LV enable tracking HV enable

pluggee, 2017-02-08:
- Change INA filter resistors to less than 10 ohms

pluggee, 2017-02-09:
- Connect R69 to 3.3V, NOT ground

pluggee, 2017-02-09:
- Change EEPROM part number to (F), more common part

pluggee, 2017-02-11:
- Fix R1008 silkscreen, 1F+ instead of 1S+

pluggee, 2017-02-16:
- Set J01 address to 0000, right now it's set to 1111

pluggee, 2017-03-08:
- update push buttons with SMT

pluggee, 2017-03-24:
Completed v1.3 and merged with master

Closed 2017-03-24.

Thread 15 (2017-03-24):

Schematic symbols missing

JustAnother1, 2017-03-24:
I tried to open the schematic on Kicad 4.0.6 and get a lot of error messages regarding missing symbols / libraries. I then also see only one page. Is that the complete schematic?

Maybe you could provide a PDF of the crowd supply version?

pluggee, 2017-03-24:
@JustAnother1 , can you clone KiCADLibs and set it up as instructed in Readme.md

pluggee, 2017-03-24:
@JustAnother1 , updating Readme.md with proper instructions, stay tuned

pluggee, 2017-03-24:
@JustAnother1 , updated Readme.md, please try again and tell me if you have any trouble

pluggee, 2017-03-24:
@JustAnother1 , added schematics PDF for your convenience

Closed 2017-03-24.

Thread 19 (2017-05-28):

v1.3.3 updates

pluggee, 2017-05-28:
- change R5 to 75Ω instead of 1k, that improved the brightness of 3.3V LED
- increase through hole silk screen clearance

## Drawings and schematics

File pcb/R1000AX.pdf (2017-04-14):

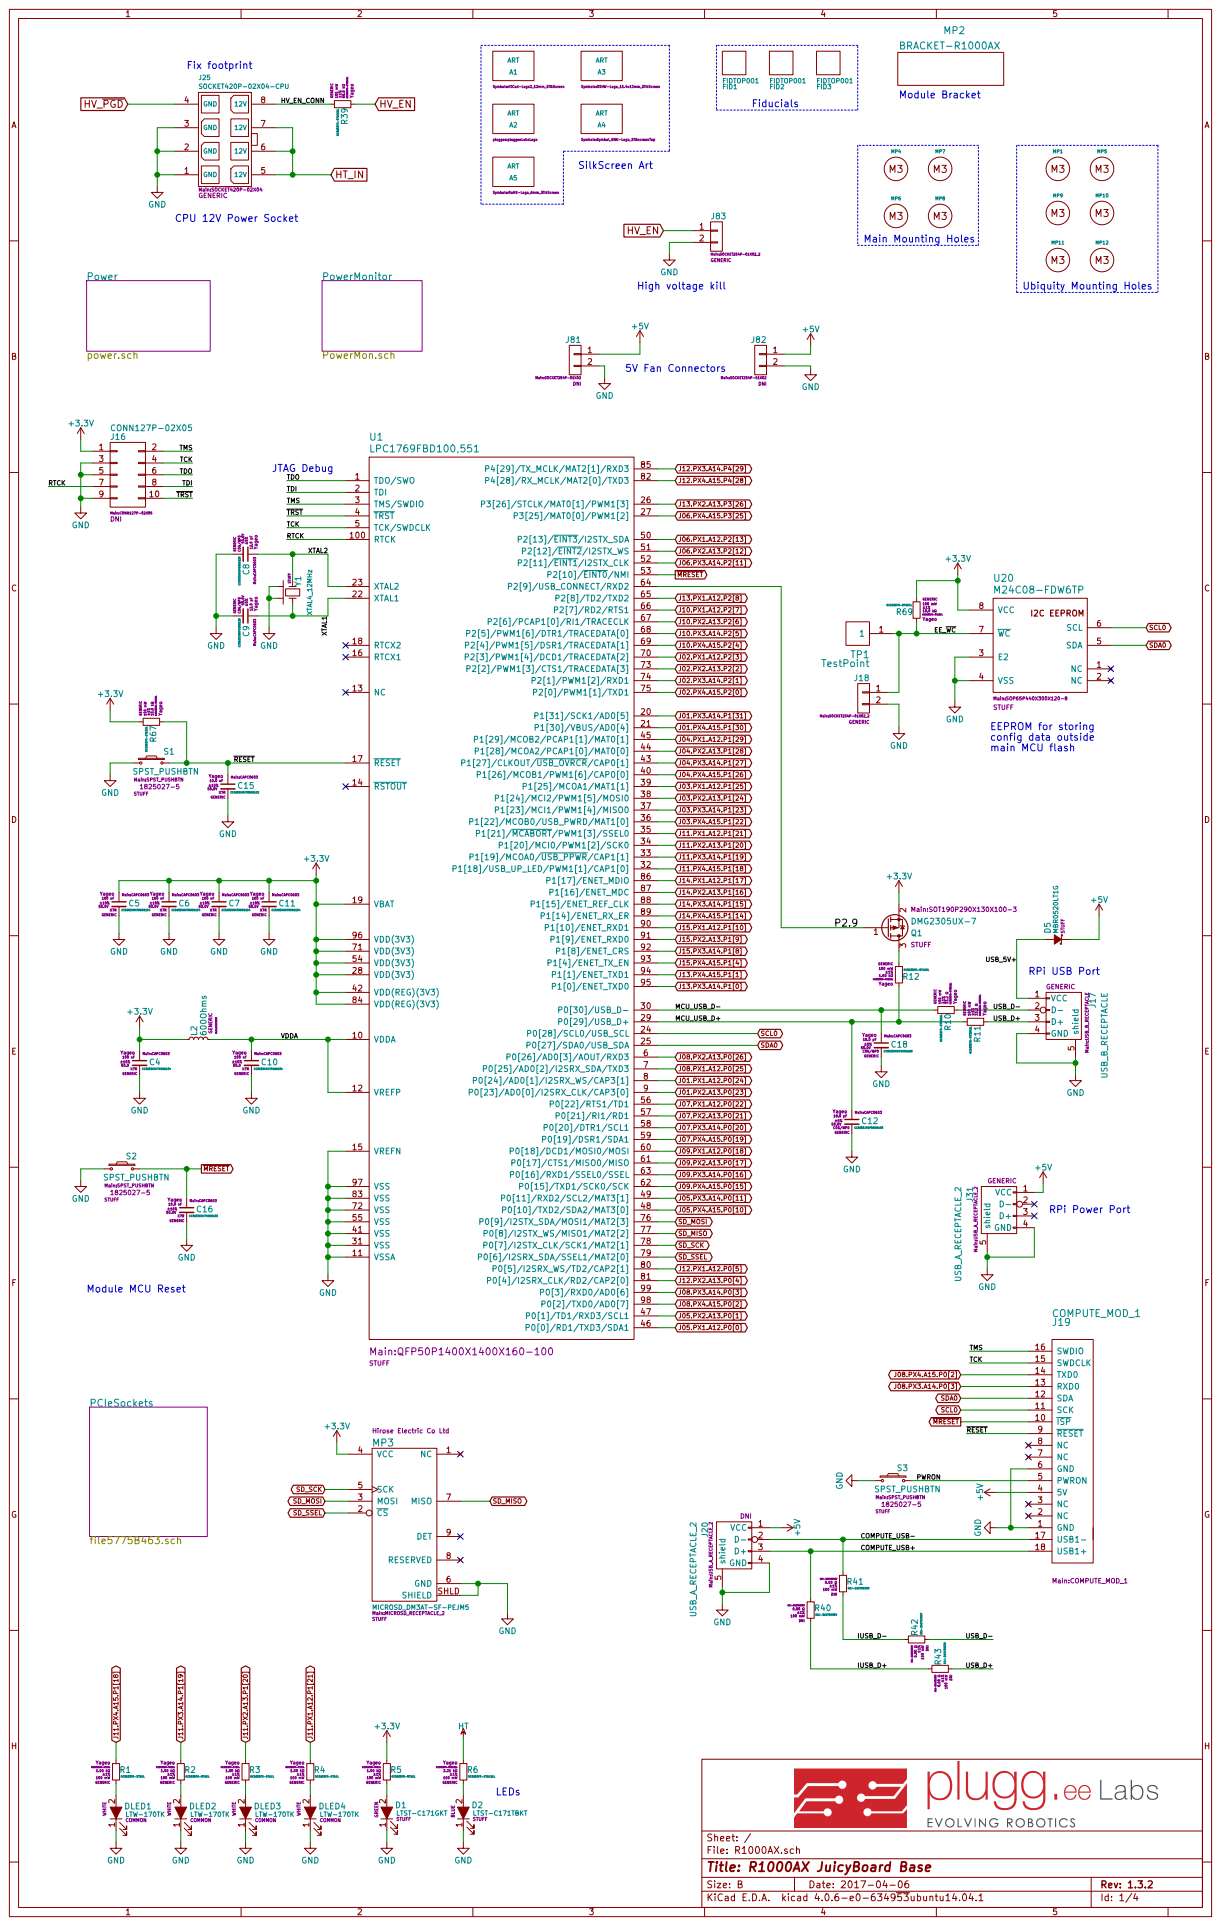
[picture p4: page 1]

PowerMonitor PowerMon.sch Fix footprint

TDI TRST RTCK GND

5 J31 USB_A_RECEPTACLE_2 Main:USB_A_RECEPTACLE_2 GENERIC VCC 1 D- 2 D+ 3 GND 4 shield

SD_SSEL +3.3V
MICROSD_DM3AT-SF-PEJM5 Main:MICROSD_RECEPTACLE_2 Hirose Electric Co Ltd

File: R1000AX.sch Sheet: / PCIeSockets

Id: 1/4 Title: R1000AX JuicyBoard Base

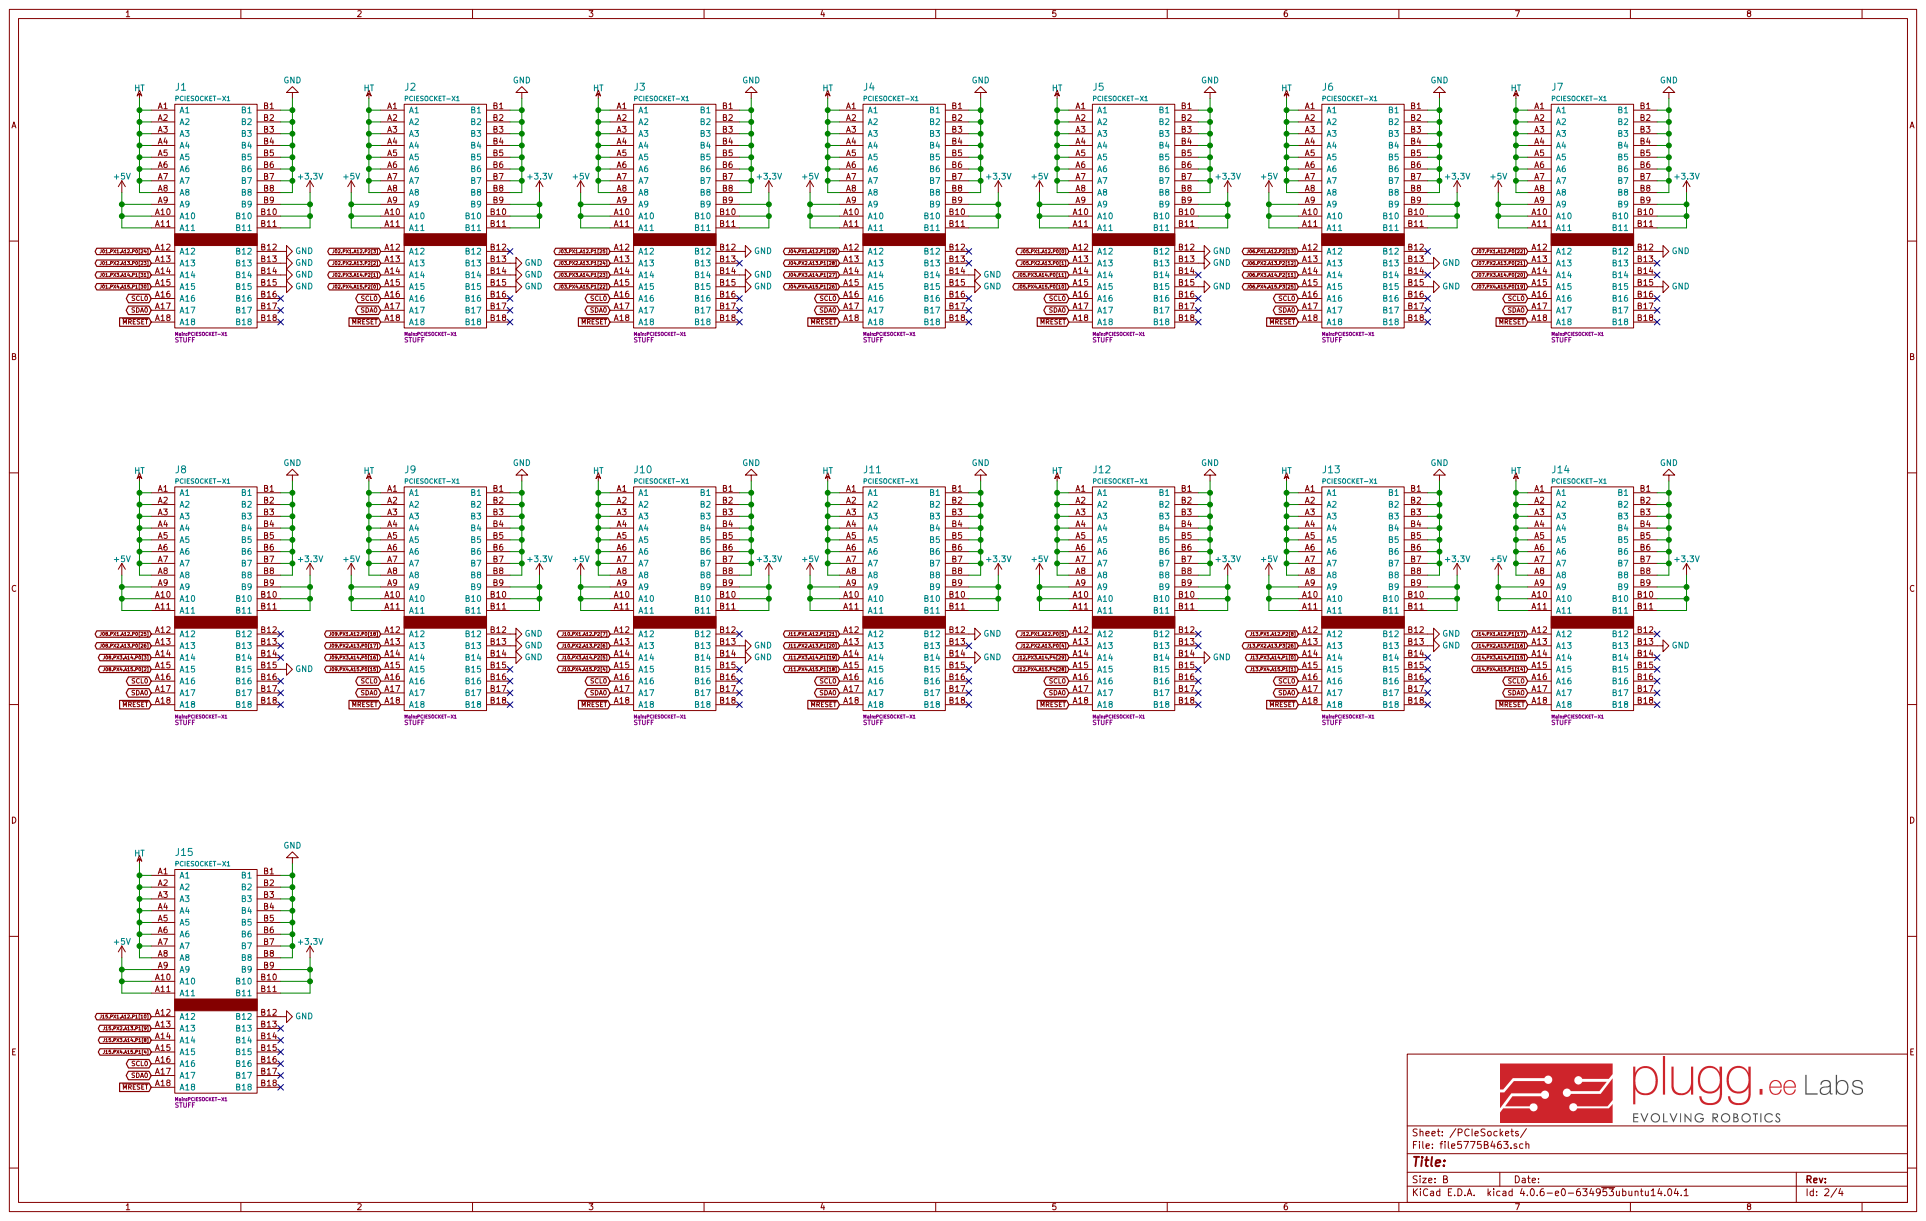
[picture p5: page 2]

J02.PX1.A12.P2[3] J02.PX2.A13.P2[2] J02.PX3.A14.P2[1] J02.PX4.A15.P2[0] GND GND GND GND

PCIESOCKET-X1 Main:PCIESOCKET-X1 STUFF

Id: 2/4 Title: File: file5775B463.sch Sheet: /PCIeSockets/

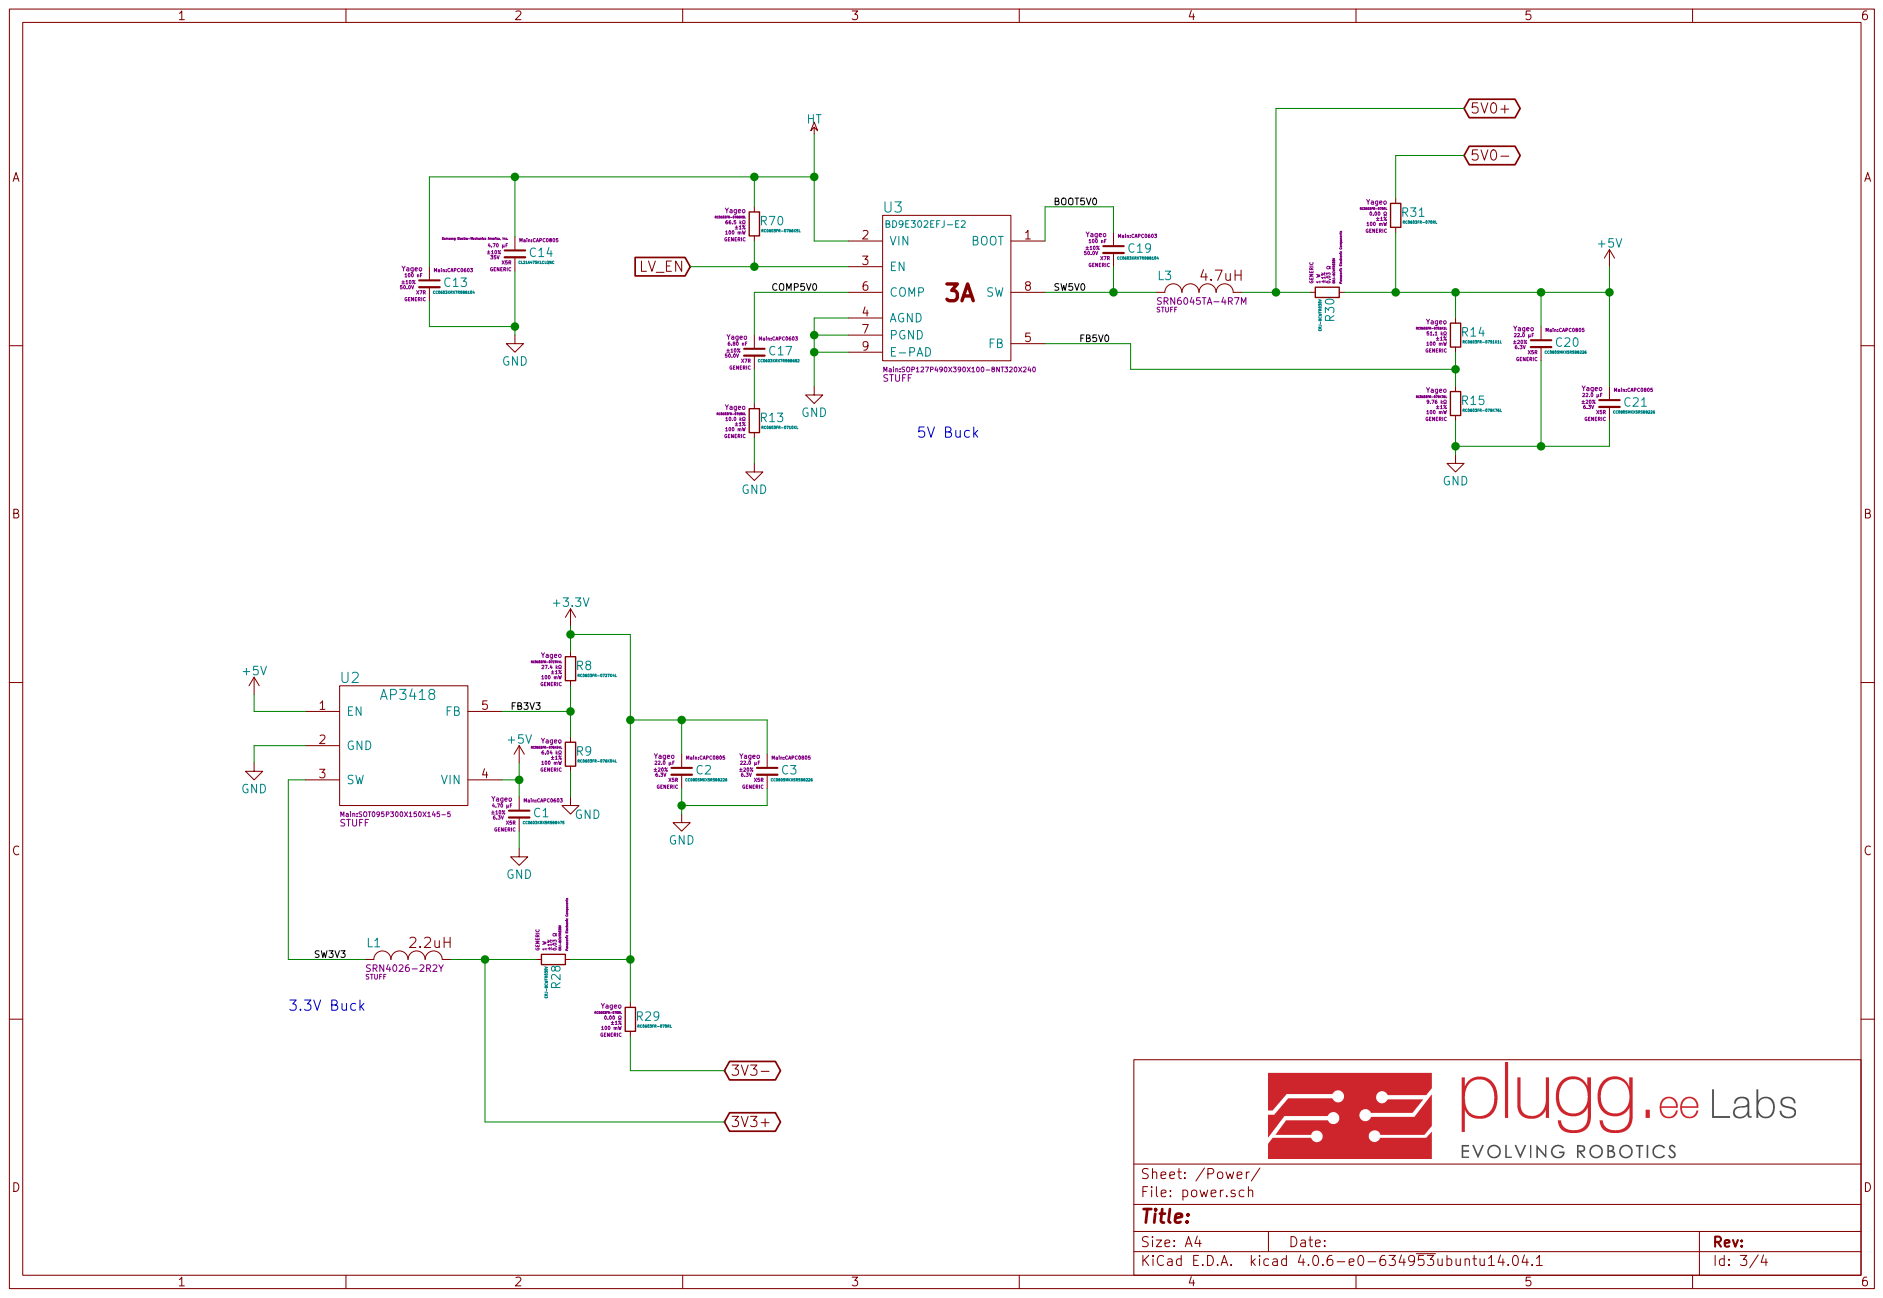
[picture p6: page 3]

CL21A475KLCLQNC Main:CAPC0805 Samsung Electro-Mechanics America, Inc. GENERIC

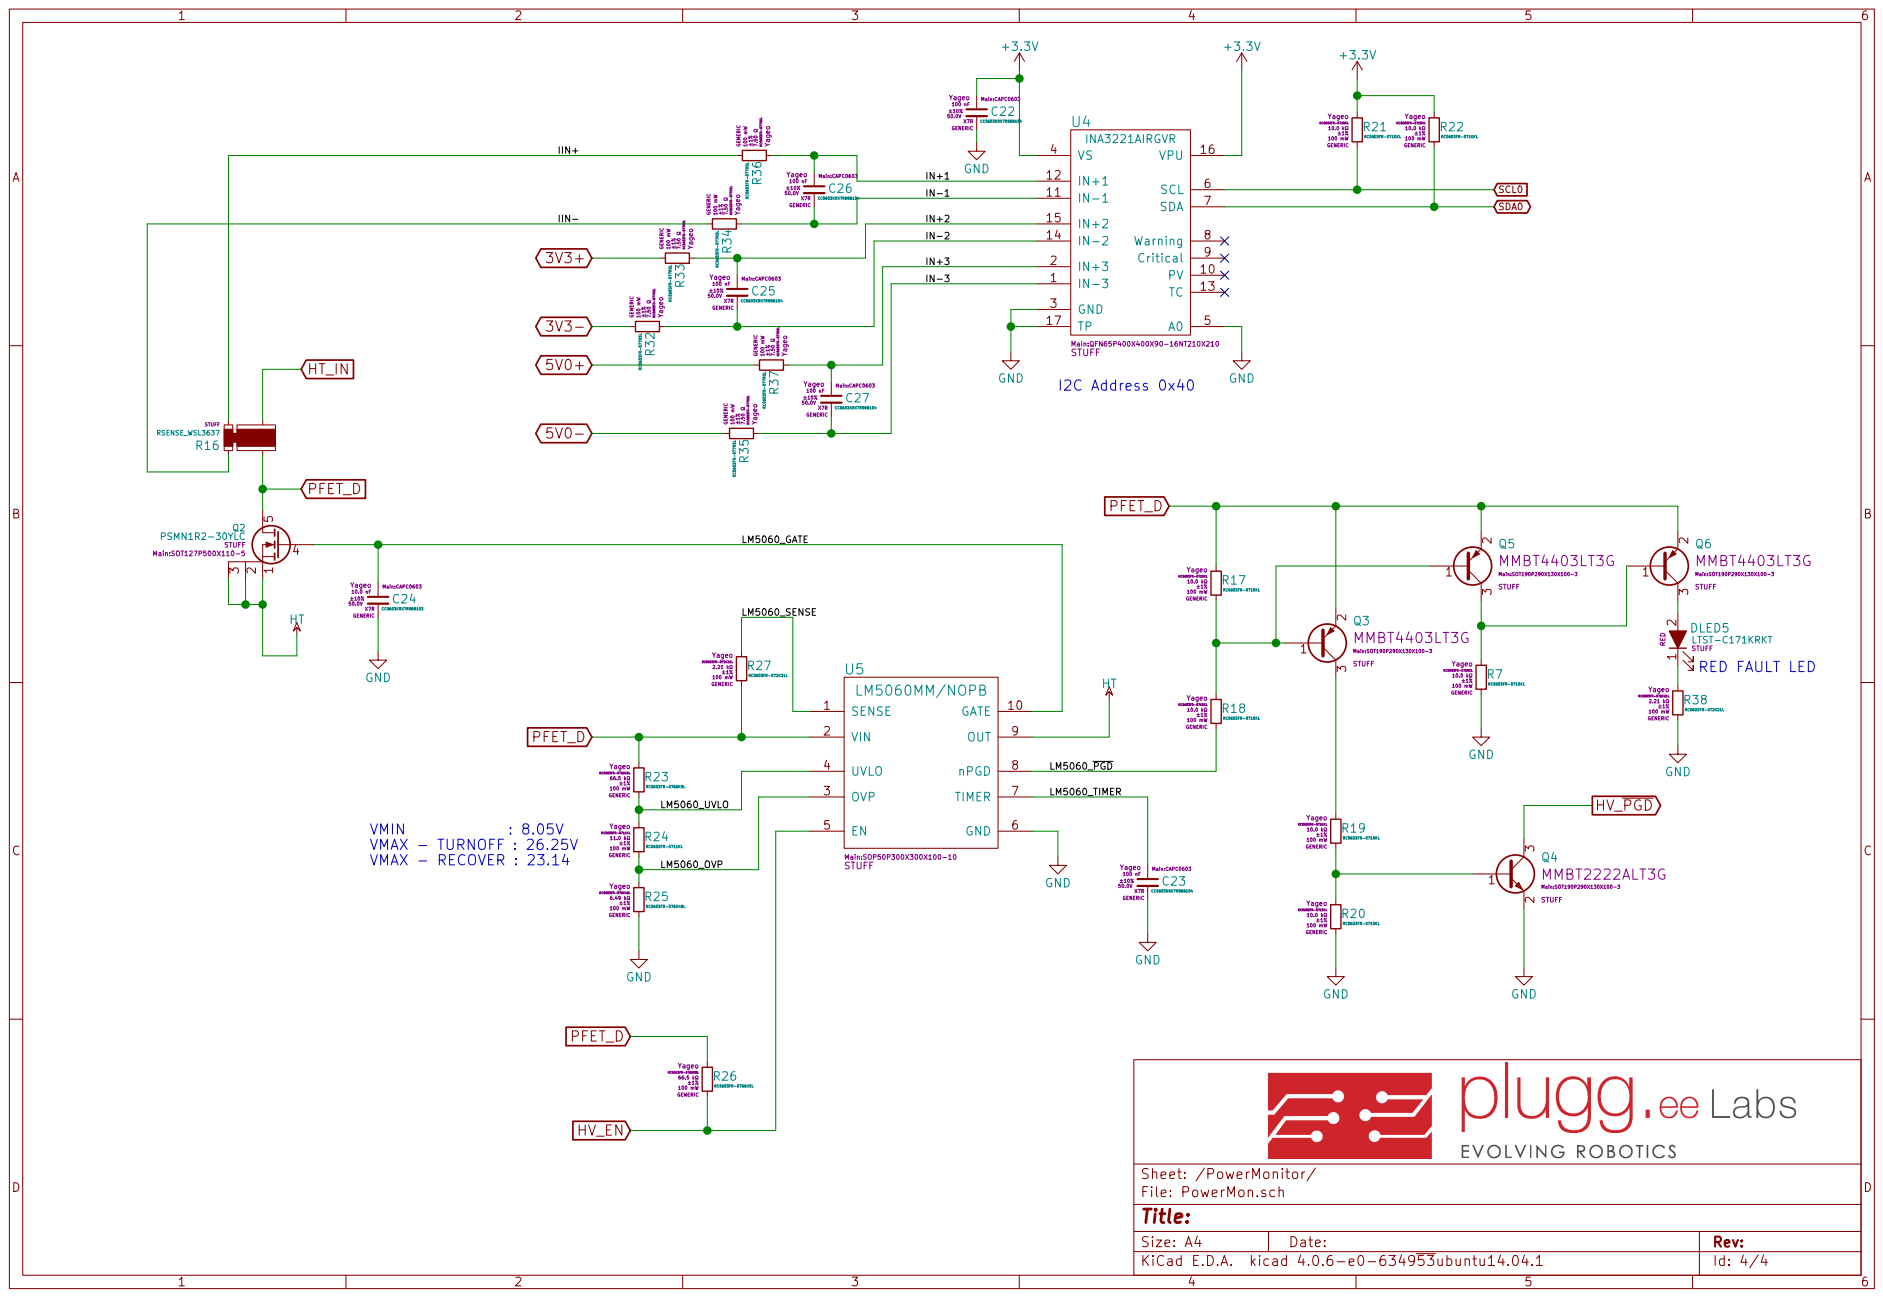
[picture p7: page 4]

Id: 4/4 Title: File: PowerMon.sch Sheet: /PowerMonitor/

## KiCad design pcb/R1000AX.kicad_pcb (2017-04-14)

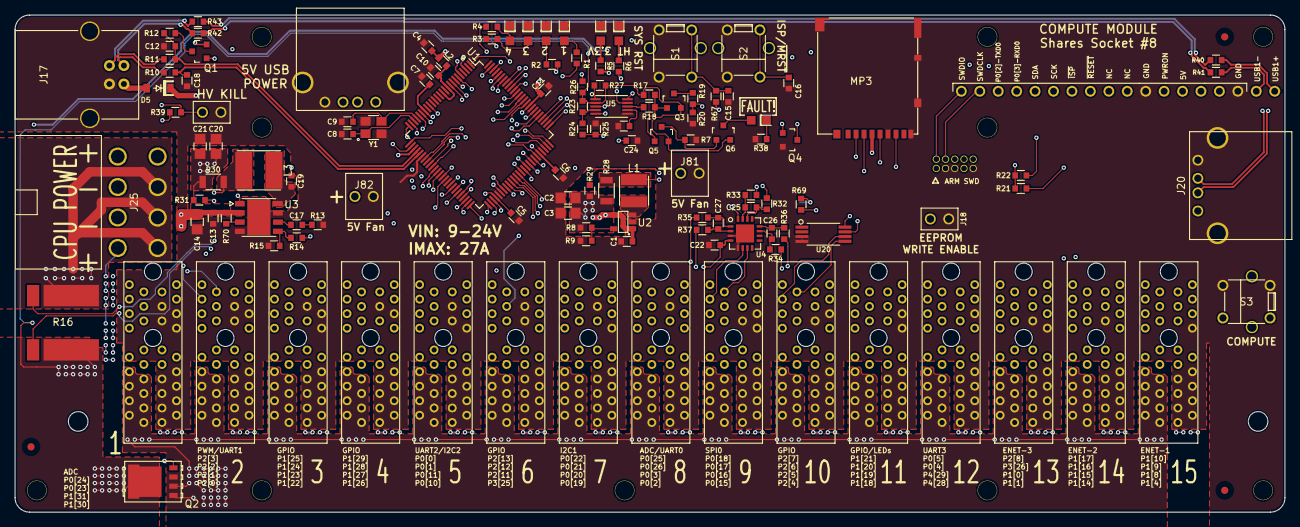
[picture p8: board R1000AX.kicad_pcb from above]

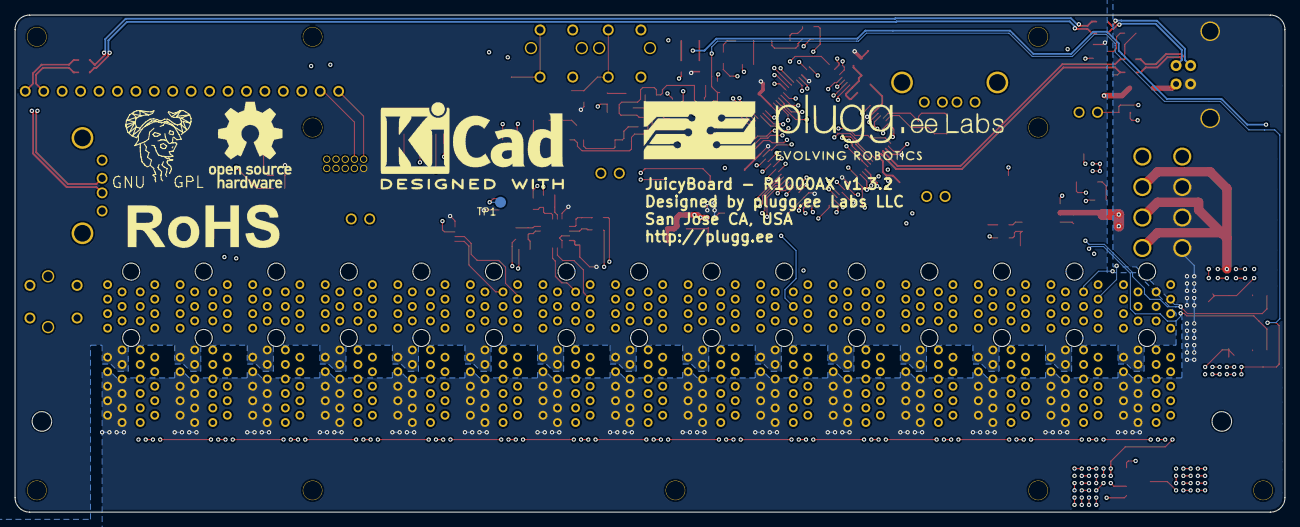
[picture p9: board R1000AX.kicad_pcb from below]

Board: 4 copper layers, 175.0 x 68.5 mm, 146 parts (6 on the bottom side), 134 nets.

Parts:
A1: ART; KiCad-Logo2_12mm_SilkScreen
A2: ART; pluggeeLabsLogo
A3: ART; OSHW-Logo_11.4x12mm_SilkScreen
A4: ART; Symbol_GNU-Logo_SilkscreenTop
A5: ART; RoHS-Logo_6mm_SilkScreen
C1: CC0603KRX5R5BB475; CAPC0603
C2, C3, C20, C21: CC0805MKX5R5BB226; CAPC0805
C4, C5, C6, C7, C10, C11, C13, C19, C22, C23, C25, C26, C27: CC0603KRX7R9BB104; CAPC0603
C8, C9: CC0603JRNPO9BN120; CAPC0603
C12, C18: CC0603JRNPO9BN180; CAPC0603
C14: CL21A475KLCLQNC; CAPC0805
C15, C16, C24: CC0603KRX7R9BB103; CAPC0603
C17: CC0603KRX7R9BB682; CAPC0603
D1: LTST-C171GKT; DIOC200X120X110
D2: LTST-C171TBKT; DIOC200X120X110
D5: MBR0520LT1G; SOD3717X135
DLED1, DLED2, DLED3, DLED4: LTW-170TK; DIOC200X120X110
DLED5: LTST-C171KRKT; DIOC200X120X110
FID1, FID2, FID3: FIDTOP001
J1, J2, J3, J4, J5, J6, J7, J8, J9, J10, J11, J12, J13, J14, J15: PCIESOCKET-X1
J16: CONN127P-02X05
J17: USB_B_RECEPTACLE
J18, J83: SOCKET254P-01X02; SOCKET254P-01X02_2
J19: COMPUTE_MOD_1
J20, J31: USB_A_RECEPTACLE
J25: SOCKET420P-02X04-CPU; SOCKET420P-02X04
J81, J82: SOCKET254P-01X02
L1: INDUCTOR_SRN4026-2R2Y; INDP400400X250
L2: 600Ohms; RESC0603
L3: INDUCTOR_SRN6045TA-4R7M; INDP600600X420
MP1, MP4, MP5, MP6, MP7, MP8, MP9, MP10, MP11, MP12: MECH_NPTH_M3
MP2: BRACKET-R1000AX
MP3: MICROSD_DM3AT-SF-PEJM5; MICROSD_RECEPTACLE_2
Q1: DMG2305UX-7; SOT190P290X130X100-3
Q2: PSMN1R2-30YLC; SOT127P500X110-5
Q3, Q5, Q6: Q_PNP_BEC; SOT190P290X130X100-3
Q4: Q_NPN_BEC; SOT190P290X130X100-3
R1, R2, R3, R4, R5: RC0603FR-071KL; RESC0603
R6, R27, R38: RC0603FR-072K21L; RESC0603
R7, R13, R17, R18, R19, R20, R21, R22, R67, R69: RC0603FR-0710KL; RESC0603
R8: RC0603FR-0727K4L; RESC0603
R9: RC0603FR-076K04L; RESC0603
R10, R11: RC0603FR-0733R2L; RESC0603
R12: RC0603FR-071K5L; RESC0603
R14: RC0603FR-0751K1L; RESC0603
R15: RC0603FR-079K76L; RESC0603
R16: RSENSE_WSL3637; RESC940914X064
R23, R26, R39, R70: RC0603FR-0766K5L; RESC0603
R24: RC0603FR-0711KL; RESC0603
R25: RC0603FR-076K49L; RESC0603
R28, R30: ERJ-8CWFR030V; RESC1206
R29, R31: RC0603FR-070RL; RESC0603
R32, R33, R34, R35, R36, R37: RC0603FR-077R5L; RESC0603
R40, R41, R42, R43: ERJ-3GEY0R00V; RESC0603
S1, S2, S3: SPST_PUSHBTN
TP1: TestPoint; TestPoint000
U1: LPC1769FBD100,551; QFP50P1400X1400X160-100
U2: AP3418; SOT095P300X150X145-5
U3: BD9E302EFJ-E2; SOP127P490X390X100-8NT320X240
U4: INA3221AIRGVR; QFN65P400X400X90-16NT210X210
U5: LM5060MM/NOPB; SOP50P300X300X100-10
U20: M24C08-FDW6TP; SOP65P440X300X120-8
Y1: XTAL4_12MHz; XTAL320X250X100

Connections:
3V3+: L1.2, R28.2, R33.2
3V3-: R29.2, R32.2
5V0+: L3.2, R30.2, R37.2
5V0-: R31.1, R35.2
+3V3: C2.1, C3.1, C4.1, C5.1, C6.1, C7.1, C11.1, C22.1, J1.B9, J1.B10, J1.B11, J2.B9, J2.B10, J2.B11, J3.B9, J3.B10, J3.B11, J4.B9, J4.B10, J4.B11, J5.B9, J5.B10, J5.B11, J6.B9, J6.B10, J6.B11, J7.B9, J7.B10, J7.B11, J8.B9, J8.B10, J8.B11, J9.B9, J9.B10, J9.B11, J10.B9, J10.B10, J10.B11, J11.B9, J11.B10, J11.B11, J12.B9, J12.B10, J12.B11, J13.B9, J13.B10, J13.B11, J14.B9, J14.B10, J14.B11, J15.B9, J15.B10, J15.B11, J16.1, L2.1, MP3.4, Q1.2, R5.1, R8.1, R21.1, R22.1, R28.1, R29.1, R67.2, R69.2, U1.19, U1.28, U1.42, U1.54, U1.71, U1.84, U1.96, U4.4, U4.16, U20.8
+5V: C1.1, C20.1, C21.1, D5.1, J1.A9, J1.A10, J1.A11, J2.A9, J2.A10, J2.A11, J3.A9, J3.A10, J3.A11, J4.A9, J4.A10, J4.A11, J5.A9, J5.A10, J5.A11, J6.A9, J6.A10, J6.A11, J7.A9, J7.A10, J7.A11, J8.A9, J8.A10, J8.A11, J9.A9, J9.A10, J9.A11, J10.A9, J10.A10, J10.A11, J11.A9, J11.A10, J11.A11, J12.A9, J12.A10, J12.A11, J13.A9, J13.A10, J13.A11, J14.A9, J14.A10, J14.A11, J15.A9, J15.A10, J15.A11, J19.4, J20.1, J31.1, J81.1, J82.1, R14.1, R30.1, R31.2, U2.1, U2.4
/COMPUTE_USB+: J19.18, J20.3, R40.1
/COMPUTE_USB-: J19.17, J20.2, R41.1
/EE_~WC: J18.1, R69.1, TP1.1, U20.7
/HV_EN_CONN: J25.8, R39.2
/IUSB_D+: R40.2, R43.1
/IUSB_D-: R41.2, R42.1
/MCU_USB_D+: C12.1, R11.2, R12.1, U1.29
/MCU_USB_D-: C18.1, R10.2, U1.30
/P2.9: Q1.1, U1.64
/PWRON: J19.5, S3.2
/Power/BOOT5V0: C19.1, U3.1
/Power/COMP5V0: C17.1, U3.6
/Power/FB3V3: R8.2, R9.1, U2.5
/Power/FB5V0: R14.2, R15.1, U3.5
/Power/SW3V3: L1.1, U2.3
/Power/SW5V0: C19.2, L3.1, U3.8
/PowerMonitor/IIN+: R16.3, R36.2
/PowerMonitor/IIN-: R16.4, R34.2
/PowerMonitor/IN+1: C26.1, R36.1, U4.12
/PowerMonitor/IN+2: C25.1, R33.1, U4.15
/PowerMonitor/IN+3: C27.1, R37.1, U4.2
/PowerMonitor/IN-1: C26.2, R34.1, U4.11
/PowerMonitor/IN-2: C25.2, R32.1, U4.14
/PowerMonitor/IN-3: C27.2, R35.1, U4.1
/PowerMonitor/LM5060_GATE: C24.1, Q2.4, U5.10
/PowerMonitor/LM5060_OVP: R24.2, R25.1, U5.3
/PowerMonitor/LM5060_SENSE: R27.1, U5.1
/PowerMonitor/LM5060_TIMER: C23.1, U5.7
/PowerMonitor/LM5060_UVLO: R23.2, R24.1, U5.4
/PowerMonitor/LM5060_~PGD: R18.2, U5.8
/TCK: J16.4, J19.15, U1.5
/TDO: J16.6, U1.1
/TMS: J16.2, J19.16, U1.3
/USB_5V+: D5.2, J17.1
/USB_D+: J17.3, R11.1, R43.2
/USB_D-: J17.2, R10.1, R42.2
/VDDA: C10.1, L2.2, U1.10, U1.12
/XTAL1: C9.1, U1.22, Y1.3
/XTAL2: C8.1, U1.23, Y1.1
/~RESET: C15.1, J19.9, R67.1, S1.2, U1.17
GND: C1.2, C2.2, C3.2, C4.2, C5.2, C6.2, C7.2, C8.2, C9.2, C10.2, C11.2, C12.2, C13.2, C14.2, C15.2, C16.2, C18.2, C20.2, C21.2, C22.2, C23.2, C24.2, D1.1, D2.1, DLED1.1, DLED2.1, DLED3.1, DLED4.1, J1.B1, J1.B2, J1.B3, J1.B4, J1.B5, J1.B6, J1.B7, J1.B8, J1.B12, J1.B13, J1.B14, J1.B15, J2.B1, J2.B2, J2.B3, J2.B4, J2.B5, J2.B6, J2.B7, J2.B8, J2.B13, J2.B14, J2.B15, J3.B1, J3.B2, J3.B3, J3.B4, J3.B5, J3.B6, J3.B7, J3.B8, J3.B12, J3.B14, J3.B15, J4.B1, J4.B2, J4.B3, J4.B4, J4.B5, J4.B6, J4.B7, J4.B8, J4.B14, J4.B15, J5.B1, J5.B2, J5.B3, J5.B4, J5.B5, J5.B6, J5.B7, J5.B8, J5.B12, J5.B13, J5.B15, J6.B1, J6.B2, J6.B3, J6.B4, J6.B5, J6.B6, J6.B7, J6.B8, J6.B13, J6.B15, J7.B1, J7.B2, J7.B3, J7.B4, J7.B5, J7.B6, J7.B7, J7.B8, J7.B12, J7.B15, J8.B1, J8.B2, J8.B3, J8.B4, J8.B5, J8.B6, J8.B7, J8.B8, J8.B15, J9.B1, J9.B2, J9.B3, J9.B4, J9.B5, J9.B6, J9.B7, J9.B8, J9.B12, J9.B13, J9.B14, J10.B1, J10.B2, J10.B3, J10.B4, J10.B5, J10.B6, J10.B7, J10.B8, J10.B13, J10.B14, J11.B1, J11.B2, J11.B3, J11.B4, J11.B5, J11.B6, J11.B7, J11.B8, J11.B12, J11.B14, J12.B1, J12.B2, J12.B3, J12.B4, J12.B5, J12.B6, J12.B7, J12.B8, J12.B14, J13.B1, J13.B2, J13.B3, J13.B4, J13.B5, J13.B6, J13.B7, J13.B8, J13.B12, J13.B13, J14.B1, J14.B2, J14.B3, J14.B4, J14.B5, J14.B6, J14.B7, J14.B8, J14.B13, J15.B1, J15.B2, J15.B3, J15.B4, J15.B5, J15.B6, J15.B7, J15.B8, J15.B12, J16.3, J16.5, J16.9, J17.4, J17.5, J18.2, J19.1, J19.6, J20.4, J20.5, J25.1, J25.2, J25.3, J31.4, J31.5, J81.2, J82.2, J83.2, MP3.6, MP3.SHLD, Q4.2, R7.2, R9.2, R13.2, R15.2, R20.2, R25.2, R38.2, S1.1, S2.1, S3.1, U1.11, U1.15, U1.31, U1.41, U1.55, U1.72, U1.83, U1.97, U2.2, U3.4, U3.7, U3.9, U4.3, U4.5, U4.17, U5.6, U20.3, U20.4, Y1.2, Y1.4
HT: C13.1, C14.1, J1.A1, J1.A2, J1.A3, J1.A4, J1.A5, J1.A6, J1.A7, J1.A8, J2.A1, J2.A2, J2.A3, J2.A4, J2.A5, J2.A6, J2.A7, J2.A8, J3.A1, J3.A2, J3.A3, J3.A4, J3.A5, J3.A6, J3.A7, J3.A8, J4.A1, J4.A2, J4.A3, J4.A4, J4.A5, J4.A6, J4.A7, J4.A8, J5.A1, J5.A2, J5.A3, J5.A4, J5.A5, J5.A6, J5.A7, J5.A8, J6.A1, J6.A2, J6.A3, J6.A4, J6.A5, J6.A6, J6.A7, J6.A8, J7.A1, J7.A2, J7.A3, J7.A4, J7.A5, J7.A6, J7.A7, J7.A8, J8.A1, J8.A2, J8.A3, J8.A4, J8.A5, J8.A6, J8.A7, J8.A8, J9.A1, J9.A2, J9.A3, J9.A4, J9.A5, J9.A6, J9.A7, J9.A8, J10.A1, J10.A2, J10.A3, J10.A4, J10.A5, J10.A6, J10.A7, J10.A8, J11.A1, J11.A2, J11.A3, J11.A4, J11.A5, J11.A6, J11.A7, J11.A8, J12.A1, J12.A2, J12.A3, J12.A4, J12.A5, J12.A6, J12.A7, J12.A8, J13.A1, J13.A2, J13.A3, J13.A4, J13.A5, J13.A6, J13.A7, J13.A8, J14.A1, J14.A2, J14.A3, J14.A4, J14.A5, J14.A6, J14.A7, J14.A8, J15.A1, J15.A2, J15.A3, J15.A4, J15.A5, J15.A6, J15.A7, J15.A8, Q2.1, Q2.2, Q2.3, R6.1, R70.1, U3.2, U5.9
HT_IN: J25.5, J25.6, J25.7, R16.1
HV_EN: J83.1, R26.2, R39.1, U5.5
HV_~PGD: J25.4, Q4.3
J01.PX1.A12.P0[24]: J1.A12, U1.8
J01.PX2.A13.P0[23]: J1.A13, U1.9
J01.PX3.A14.P1[31]: J1.A14, U1.20
J01.PX4.A15.P1[30]: J1.A15, U1.21
J02.PX1.A12.P2[3]: J2.A12, U1.70
J02.PX2.A13.P2[2]: J2.A13, U1.73
J02.PX3.A14.P2[1]: J2.A14, U1.74
J02.PX4.A15.P2[0]: J2.A15, U1.75
J03.PX1.A12.P1[25]: J3.A12, U1.39
J03.PX2.A13.P1[24]: J3.A13, U1.38
J03.PX3.A14.P1[23]: J3.A14, U1.37
J03.PX4.A15.P1[22]: J3.A15, U1.36
J04.PX1.A12.P1[29]: J4.A12, U1.45
J04.PX2.A13.P1[28]: J4.A13, U1.44
J04.PX3.A14.P1[27]: J4.A14, U1.43
J04.PX4.A15.P1[26]: J4.A15, U1.40
J05.PX1.A12.P0[0]: J5.A12, U1.46
J05.PX2.A13.P0[1]: J5.A13, U1.47
J05.PX3.A14.P0[11]: J5.A14, U1.49
J05.PX4.A15.P0[10]: J5.A15, U1.48
J06.PX1.A12.P2[13]: J6.A12, U1.50
J06.PX2.A13.P2[12]: J6.A13, U1.51
J06.PX3.A14.P2[11]: J6.A14, U1.52
J06.PX4.A15.P3[25]: J6.A15, U1.27
J07.PX1.A12.P0[22]: J7.A12, U1.56
J07.PX2.A13.P0[21]: J7.A13, U1.57
J07.PX3.A14.P0[20]: J7.A14, U1.58
J07.PX4.A15.P0[19]: J7.A15, U1.59
J08.PX1.A12.P0[25]: J8.A12, U1.7
J08.PX2.A13.P0[26]: J8.A13, U1.6
J08.PX3.A14.P0[3]: J8.A14, J19.13, U1.99
J08.PX4.A15.P0[2]: J8.A15, J19.14, U1.98
J09.PX1.A12.P0[18]: J9.A12, U1.60
J09.PX2.A13.P0[17]: J9.A13, U1.61
J09.PX3.A14.P0[16]: J9.A14, U1.63
J09.PX4.A15.P0[15]: J9.A15, U1.62
J10.PX1.A12.P2[7]: J10.A12, U1.66
J10.PX2.A13.P2[6]: J10.A13, U1.67
J10.PX3.A14.P2[5]: J10.A14, U1.68
J10.PX4.A15.P2[4]: J10.A15, U1.69
J11.PX1.A12.P1[21]: J11.A12, R4.1, U1.35
J11.PX2.A13.P1[20]: J11.A13, R3.1, U1.34
J11.PX3.A14.P1[19]: J11.A14, R2.1, U1.33
J11.PX4.A15.P1[18]: J11.A15, R1.1, U1.32
J12.PX1.A12.P0[5]: J12.A12, U1.80
J12.PX2.A13.P0[4]: J12.A13, U1.81
J12.PX3.A14.P4[29]: J12.A14, U1.85
J12.PX4.A15.P4[28]: J12.A15, U1.82
J13.PX1.A12.P2[8]: J13.A12, U1.65
J13.PX2.A13.P3[26]: J13.A13, U1.26
J13.PX3.A14.P1[0]: J13.A14, U1.95
J13.PX4.A15.P1[1]: J13.A15, U1.94
J14.PX1.A12.P1[17]: J14.A12, U1.86
J14.PX2.A13.P1[16]: J14.A13, U1.87
J14.PX3.A14.P1[15]: J14.A14, U1.88
J14.PX4.A15.P1[14]: J14.A15, U1.89
J15.PX1.A12.P1[10]: J15.A12, U1.90
J15.PX2.A13.P1[9]: J15.A13, U1.91
J15.PX3.A14.P1[8]: J15.A14, U1.92
J15.PX4.A15.P1[4]: J15.A15, U1.93
LV_EN: R70.2, U3.3
unnamed: C17.2, R13.1
unnamed: D1.2, R5.2
unnamed: D2.2, R6.2
unnamed: DLED1.2, R1.2
unnamed: DLED2.2, R2.2
unnamed: DLED3.2, R3.2
unnamed: DLED4.2, R4.2
unnamed: DLED5.1, R38.1
unnamed: DLED5.2, Q6.3
unnamed: Q1.3, R12.2
unnamed: Q3.1, Q5.1, R17.2, R18.1
unnamed: Q3.3, R19.1
unnamed: Q4.1, R19.2, R20.1
unnamed: Q5.3, Q6.1, R7.1
PFET_D: Q2.5, Q3.2, Q5.2, Q6.2, R16.2, R17.1, R23.1, R26.1, R27.2, U5.2
SCL0: J1.A16, J2.A16, J3.A16, J4.A16, J5.A16, J6.A16, J7.A16, J8.A16, J9.A16, J10.A16, J11.A16, J12.A16, J13.A16, J14.A16, J15.A16, J19.11, R21.2, U1.24, U4.6, U20.6
SDA0: J1.A17, J2.A17, J3.A17, J4.A17, J5.A17, J6.A17, J7.A17, J8.A17, J9.A17, J10.A17, J11.A17, J12.A17, J13.A17, J14.A17, J15.A17, J19.12, R22.2, U1.25, U4.7, U20.5
SD_MISO: MP3.7, U1.77
SD_MOSI: MP3.3, U1.76
SD_SCK: MP3.5, U1.78
SD_SSEL: MP3.2, U1.79
~MRESET: C16.1, J1.A18, J2.A18, J3.A18, J4.A18, J5.A18, J6.A18, J7.A18, J8.A18, J9.A18, J10.A18, J11.A18, J12.A18, J13.A18, J14.A18, J15.A18, J19.10, S2.2, U1.53

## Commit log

2016-07-03 moved from R1000 repo
    [R1000A.kicad_pcb, R1000A.sch, file5775B463.sch]
2016-07-09 added 4 pin board to wire
    [R1000A.kicad_pcb, R1000A.sch, file5775B463.sch]
2016-07-11 wip, added 3.3V reg
    [R1000A.kicad_pcb, R1000A.sch, file5775B463.sch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]
2016-07-12 added sheet for MCU pin mapping
    [LPC1769_pinmapping.ods, MCU_pads.xlsx]
2016-07-14 connected nets between MCU and connectors
    [LPC1769_pinmapping.ods, LPC1769_pinmapping.xlsx, R1000A.sch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]
2016-07-14 wip, 90% sch complete
    [R1000A.kicad_pcb, R1000A.sch, file5775B463.sch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]
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2016-07-17 wip, cleaned routing to retoute MCU prioritized
    [R1000A.kicad_pcb]
2016-07-19 layout wip, need to plan mechanical and lug placement
    [R1000A.kicad_pcb, R1000A.sch, file5775B463.sch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]
2016-07-21 tagging to remove lugs
    [R1000A.kicad_pcb, R1000A.sch, file5775B463.sch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]
2016-07-22 layout wip, need to resolve USB ports mix up
    [R1000A.kicad_pcb, R1000A.sch, file5775B463.sch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]
2016-07-22 wip: layout complete, need to complete markings
    [R1000A.kicad_pcb, R1000A.sch]
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2016-07-26 regenerated gerbers after fixing silk screen, adding P1.1
    [R1000A-B.Cu.gbr, R1000A-B.Mask.gbr, R1000A-B.Paste.gbr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]
2016-07-30 releasing 1.0.2b, added USB softconnect structure and fixed silkscreen
    [LPC1769_pinmapping.ods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]
2016-08-02 releasding v1.0.3b, modifications for manufacturability
    [R1000A-B.Cu.gbr, R1000A-B.Mask.gbr, R1000A-B.Paste.gbr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]
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2016-09-22 updated pinlist with V1.1, wip
    [LPC1769_pinmapping.xlsx]
2016-09-23 wip, routed all slots
    [R1000A.kicad_pcb, R1000A.sch, file5775B463.sch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]
2016-09-24 wip, submitted first placement review
    [R1000A.kicad_pcb, R1000A.sch, file5775B463.sch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]
2016-09-28 wip, completed a round of placement, mini board is 122mm x 65mm
    [R1000A.kicad_pcb, R1000A.sch, file5775B463.sch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]
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2016-09-29 wip, replaced type-B with mini type-B
    [R1000A.kicad_pcb, R1000A.sch]
2016-09-30 wip, added silk screen notes
    [R1000A.kicad_pcb, R1000A.sch, power.sch]
2016-10-02 created bbox 3d model of board
    [R1000A.kicad_pcb, R1000A.sch, R1000A_bbox.FCStd]
2016-10-02 updated pinlist, sorted pins in scrap tab
    [LPC1769_pinmapping.xlsx]
2016-10-03 cleaned up silk screen
    moved microSD to top layer and expanded the board a little to the right
    [R1000A.kicad_pcb, R1000A.sch, file5775B463.sch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]
2016-10-03 cleaned up with full SD card receptacle
    [R1000A.kicad_pcb, R1000A.sch, file5775B463.sch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]
2016-10-03 fixed one more silk screen
    [R1000A.kicad_pcb]
2016-10-04 added slot numbers in silk screen
    [R1000A.kicad_pcb]
2016-10-04 removed date tagged gerbers directories
    [R1000A-B.Cu.gbr, R1000A-B.Mask.gbr, R1000A-B.Paste.gbr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]
2016-10-04 exported and verified gerbers
    [R1000A-B.Cu.gbr, R1000A-B.Mask.gbr, R1000A-B.Paste.gbr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]
2016-10-05 fixed led trace connections to allow easier reduction to 10 slot
    [R1000A-B.Cu.gbr, R1000A-B.Mask.gbr, R1000A-B.Paste.gbr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]
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2016-10-05 changed C14 to 0805
    [R1000A.kicad_pcb, R1000A.sch, file5775B463.sch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]
2016-10-06 removed hanging unconnected nets
    [R1000A.kicad_pcb]
2016-10-09 fixed RPi footprint
    [R1000A-B.Cu.gbr, R1000A-B.Mask.gbr, R1000A-B.Paste.gbr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]
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2016-10-13 completed layout, still need to finalize resistor values (no new netlist)
    [PowerMon.sch, R1000A.kicad_pcb, R1000A.sch]
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2016-10-13 updated layout and gerbers, moved C24 from under the bracket
    [R1000A-B.Cu.gbr, R1000A-B.Mask.gbr, R1000A-B.Paste.gbr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]
2016-10-13 added mode thermal vias to FET source
    [R1000A-B.Cu.gbr, R1000A-B.Mask.gbr, R1000A-B.Paste.gbr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]
2016-10-27 added lm5060 calculation sheet
    [LM5060_calculation.xlsx]
2016-10-28 updated calculations from datasheet
    [LM5060_calculation.xlsx]
2016-11-01 updated and verified LM5060 calculations vs measurements
    [LM5060_calculation.xlsx]
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2016-11-02 removed UART header, moved LEDs to front, wip
    [PowerMon.sch, R1000A.kicad_pcb, R1000A.sch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]
2016-11-02 wip, performing 1.1.1 fixes
    [R1000A.kicad_pcb]
2016-11-03 wip, need to add sense resistors for supplies
    [PowerMon.sch, R1000A.kicad_pcb, R1000A.sch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]
2016-11-29 updated pin map with swapping ISP0 and MRESET
    [LPC1769_pinmapping.xlsx]
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2016-12-12 now ISP and MRESET have the same function in schematics
    [R1000A.kicad_pcb, R1000A.sch]
2016-12-12 updated pinlist, MRESET and ISP0 are the same function now, this prevents interrupting any of the modules if the user pushes ISP0 button
    [LPC1769_pinmapping.xlsx]
2016-12-12 cleaned layout and ready for 1.2.0 release, need to finalize checks
    [PowerMon.sch, R1000A.kicad_pcb, R1000A.sch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]
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2016-12-14 added low voltage kill switch with option to track hv kill, or keep LV on all the time. improved ground path from connector, re-exported gerbers for release
    [PowerMon.sch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]
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2016-12-25 added fiducials and re-laid ground and high tension planes
    [R1000A.kicad_pcb, R1000A.sch]
2016-12-29 fixed dfm orientation for L3
    [R1000A.kicad_pcb]
2016-12-29 wip, added eeprom and test point for write protecting ROM during normal operation
    [PowerMon.sch, R1000A.kicad_pcb, R1000A.sch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]
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2017-01-11 updated BOM generation with semi-colons isntead of comas
    [R1000A_BOM.csv]
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2017-03-23 wip, need to correct footprints
    [PowerMon.sch, R1000A.kicad_pcb, R1000A.sch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]
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2017-03-24 renamed files to match R1000AX, cleaned up, re-plotted gerbers, generated schematics PDF
    [PowerMon.sch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]
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2017-03-30 added socket for CHIP and other compute modules
    [PowerMon.sch, R1000AX.kicad_pcb, R1000AX.sch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]
2017-03-31 completed layout with internet connected module, updated gerbers and bom
    [PowerMon.sch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]
2017-03-31 ensured distance margin between last module and host usb connector
    [R1000AX-B.Cu.gbr, R1000AX-B.Mask.gbr, R1000AX-B.Paste.gbr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]
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2017-03-31 regenerated BOM with new script that groups components
    [R1000AX_BOM.csv, R1000AX_BOM.ods, R1000AX_BOM.xlsx]
2017-04-01 completed v1.3.1, implemented changes based on second crowdsupply update
    [R1000AX-B.Cu.gbr, R1000AX-B.Mask.gbr, R1000AX-B.Paste.gbr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]
2017-04-02 added host USB to LPC USB jump option using a diffpair
    [PowerMon.sch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]
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2017-04-04 fixed 3d model
    [R1000AX.kicad_pcb]
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2017-04-04 moved SD card more towards edge, making it accessible from case
    [R1000AX.kicad_pcb]
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2017-04-06 fixed dimensions for tactile switches
    [R1000AX-B.Cu.gbr, R1000AX-B.Mask.gbr, R1000AX-B.Paste.gbr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]
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2017-04-11 replaced molex USB connector with a common connector, all USBs are low profile now
    [R1000AX-B.Cu.gbr, R1000AX-B.Mask.gbr, R1000AX-B.Paste.gbr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]
2017-04-11 fixed c7 location
    [R1000AX-B.Cu.gbr, R1000AX-B.Mask.gbr, R1000AX-B.Paste.gbr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]
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
